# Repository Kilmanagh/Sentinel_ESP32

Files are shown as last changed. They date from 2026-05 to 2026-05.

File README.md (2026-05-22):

# Sentinel ESP32

Sentinel is an ESP32-based multi-sensor node built around ESPHome and Home Assistant.

The active implementation lives in `esphome/sentinel.yaml`. The old PlatformIO project in `pio-ARCHIVE/` is deprecated and is no longer the source of truth.

## Current firmware

- Active config: `esphome/sentinel.yaml`
- Secrets file: `esphome/secrets.yaml`
- Board target: `esp32dev`
- Framework: ESPHome on Arduino
- Home Assistant integration: native ESPHome API
- Device services: Wi-Fi, OTA, web server, local fallback AP, and Home Assistant entity-based runtime tuning

## Features

- BME280 environment telemetry
- AM312 PIR motion detection with warmup, stable-detect, stable-clear, and hold timing
- MAX9814 sound intrusion detection using peak-to-peak sampling
- Reed switch door state reporting
- Sound-level calibration helpers and approximate dB display
- Smoke alarm tone and cadence detection
- Device-health diagnostics and fault indicators
- Three-pixel WS2812 status LED strip plus onboard status LED
- Runtime tuning through Home Assistant entities exposed by ESPHome

## Primary docs

- `docs/Adjustments.MD` - active ESPHome tuning, calibration, and sensor-behavior guide
- `docs/Hardware_Deliverables.md` - current hardware, pin mapping, and LED wiring summary
- `hardware/Sentinel_Baseplate_Kit_Wiring.md` - practical baseplate / Dupont wiring guide for the actual 30-pin ESP32 board and expansion kit
- `hardware/Sentinel_Baseplate_Kit_Wiring.md` also includes a Sentinel-only pin map and a first bring-up checklist for bench validation
- `docs/Sentinel_Home_Assistant_Helpers.md` - optional Home Assistant helper package for counters, mode helpers, and last-event tracking
- `docs/Sentinel_Lovelace_Dashboard.md` - dashboard layout, setup, and troubleshooting view
- `docs/Sentinel_Lovelace_Dashboard.yaml` - Lovelace YAML for the dashboard itself

## Deploy

Use ESPHome to validate and install `esphome/sentinel.yaml`.

Typical workflow:

1. Fill in `esphome/secrets.yaml` with your Wi-Fi credentials.
2. Open `esphome/sentinel.yaml` in ESPHome or the Home Assistant ESPHome add-on.
3. Validate the config.
4. Install over USB for first flash, then use OTA afterward if desired.

## Notes

- The active docs no longer use the old MQTT, serial `cfg`, or BLE watchlist workflow.
- If you need historical PlatformIO material, keep it isolated under `pio-ARCHIVE/`.

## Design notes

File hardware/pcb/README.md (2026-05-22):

# PCB Package

This directory holds PCB fabrication package assets.

## Current recommendation

For the current Sentinel hardware build, do not treat this folder as the primary assembly path.

The recommended real-world build is:

- the existing AITRIP ESP32 baseplate / expansion kit
- Dupont wiring
- the practical wiring guide in `hardware/Sentinel_Baseplate_Kit_Wiring.md`

This `hardware/pcb/` folder should currently be treated as an experimental custom-board branch and documentation artifact, not the default build path.

## Current source

- `Sentinel_Passive_Carrier.kicad_pcb`: generated KiCad board source for a passive carrier board
- `generate_passive_carrier.py`: reproducible pcbnew generator for the current board source
- `Sentinel_Passive_Carrier_drc.rpt`: latest KiCad DRC report

## Current design scope

This is a passive carrier board derived from the current wiring, schematic, and enclosure documentation.

It assumes:

- ESP32 DevKit remains off-board and connects through a wire harness header rather than a direct socket footprint
- BME280, AM312, MAX9814, reed switch, and LED strip land on generic header / terminal positions
- board outline is sized conservatively to fit within the current 95 mm x 65 mm enclosure envelope

It is useful for:

- preserving the custom PCB experiment
- future routing / layout work
- exporting fabrication files for review while the design is still being corrected

It is not yet the recommended path for:

- immediate hardware assembly
- ordering production boards
- using as the single source of truth for the active build

## Fabrication package

The `gerbers/` folder now contains real KiCad exports for the passive carrier board, including:

- copper layers
- solder mask layers
- silkscreen layers
- edge cuts
- Excellon drill file
- drill map and drill report
- KiCad gerber job file

## Validation status

The fabrication package is generated from a real board source, but the current carrier layout is not yet fully DRC-clean.

Practical meaning:

- the files are real KiCad exports
- the board is still not ready to be treated as fabrication-safe
- the DRC report must be resolved before any board order is placed

Until that happens, the active hardware reference remains the baseplate / Dupont path documented in `hardware/Sentinel_Baseplate_Kit_Wiring.md`.

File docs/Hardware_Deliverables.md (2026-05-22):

# Sentinel ESP32 Hardware Deliverables

This document outlines the current hardware components and wiring configuration for the active ESPHome-based Sentinel ESP32 node.

## Bill of Materials (BOM)

- **Microcontroller**: AITRIP ESP-WROOM-32 / ESP-32S Type-C CH340C development board, 30-pin ESP32 DevKit V1 style header layout
- **Environmental Sensor**: BME280, 3.3V I2C
- **Motion Sensor**: AM312 mini PIR, powered from 3.3V
- **Acoustic Sensor**: MAX9814 microphone amplifier, analog output to GPIO 34
- **Security Sensor**: MC-38 magnetic reed switch, normally closed, signal to GPIO 32
- **Onboard Status LED**: ESP32 onboard LED on GPIO 2
- **External Status LEDs**: 3 x WS2812 addressable LEDs chained on GPIO 25 data
- **Recommended LED protection**: 330-470 ohm series resistor on the GPIO 25 data line and 470-1000 uF capacitor across LED 5V and GND

## Hardware Configuration And Pin Mapping

The active ESPHome build uses a mixed power layout:

- Sensors use the ESP32 regulated 3.3V rail
- The external WS2812 status LED chain uses the board 5V or VIN rail
- All devices must share a common ground

### Confirmed Dev Board Header Layout

The actual board shown by the user is the common 30-pin ESP32 DevKit V1 / ESP-32S style board, not the 38-pin Espressif DevKitC layout.

With the module antenna on the left and the USB Type-C connector on the right, the header labels are:

- Top row, left to right: `3V3`, `GND`, `D15`, `D2`, `D4`, `RX2`, `TX2`, `D5`, `D18`, `D19`, `D21`, `RX0`, `TX0`, `D22`, `D23`
- Bottom row, left to right: `EN`, `VP`, `VN`, `D34`, `D35`, `D32`, `D33`, `D25`, `D26`, `D27`, `D14`, `D12`, `D13`, `GND`, `VIN`

For Sentinel, the important physical header locations are:

- `3V3`: top row, pin 1 from the left
- `GND`: top row, pin 2 from the left or bottom row, pin 14 from the left
- `VIN` / 5V: bottom row, pin 15 from the left
- `GPIO34`: bottom row, pin 4 from the left (`D34`)
- `GPIO32`: bottom row, pin 6 from the left (`D32`)
- `GPIO25`: bottom row, pin 8 from the left (`D25`)
- `GPIO27`: bottom row, pin 10 from the left (`D27`)
- `GPIO21`: top row, pin 11 from the left (`D21`)
- `GPIO22`: top row, pin 14 from the left (`D22`)
- `GPIO2`: top row, pin 4 from the left (`D2`)

| Hardware Component | Component Pin | ESP32 GPIO / Pin | Active ESPHome Use | Pin Type |
| :--- | :--- | :--- | :--- | :--- |
| **BME280** | SDA | **GPIO 21** | `i2c.sda` | I2C Data |
| **BME280** | SCL | **GPIO 22** | `i2c.scl` | I2C Clock |
| **AM312 PIR** | OUT | **GPIO 27** | `pir_raw` | Digital Input |
| **MC-38 Reed Switch (NC)** | Signal | **GPIO 32** | `Door` | Digital Input with Pull-up |
| **MAX9814** | OUT | **GPIO 34** | sound sampling path | Analog Input |
| **Onboard LED** | Internal LED | **GPIO 2** | `status_led` | Digital Status Output |
| **WS2812 LED Chain** | DIN (LED 1) | **GPIO 25** | `Status LEDs` | Addressable LED Data |

## Wiring Connection Notes

- **Sensor Power**: Connect the BME280, AM312 PIR, and MAX9814 to the **3.3V** rail and **GND**.
- **Reed Switch**: Connect one MC-38 wire to **GPIO 32** and the other to **GND**. The active ESPHome config enables the internal pull-up, so the closed switch reads low when the magnet is present.
- **Analog Input**: GPIO 34 is input-only on the ESP32 and is appropriate for the MAX9814 analog output.
- **WS2812 Status LEDs**: The external 3-pixel LED chain is not powered from 3.3V. Use the ESP32 board **5V** or **VIN** rail for LED power, connect LED ground to the shared ground rail, and feed LED 1 data from **GPIO 25**.
- **LED Data Chain**: `GPIO25 -> DIN LED 1 -> DOUT LED 1 -> DIN LED 2 -> DOUT LED 2 -> DIN LED 3`.
- **LED Color Order**: The current ESPHome build expects `GRB` for the WS2812 chain.
- **Onboard LED vs External LEDs**: The node uses both the onboard GPIO 2 LED and the external 3-pixel WS2812 chain. The onboard LED is the basic ESPHome status LED, while the three external LEDs provide the main left, center, and right status display described elsewhere in the project docs.

### Final Expected Connections

| Sentinel function | Connect to | Power source |
| :--- | :--- | :--- |
| BME280 SDA | `D21` | `3.3V` |
| BME280 SCL | `D22` | `3.3V` |
| AM312 PIR OUT | `D27` | `3.3V` |
| MAX9814 OUT | `D34` | `3.3V` |
| MC-38 reed wire 1 | `D32` | none |
| MC-38 reed wire 2 | `GND` | none |
| WS2812 DIN | `D25` through `330-470 ohm` series resistor | n/a |
| WS2812 power | dedicated `5V` breakout or `VIN` | `5V` |
| WS2812 ground | `GND` | common ground |

For the baseplate / expansion kit build, keep the baseplate `V` jumper set to `3.3V` so the shared `V` row remains safe for the BME280, PIR, and MAX9814. Do not power the WS2812 strip from that shared `V` row.

## Current Firmware-Relevant Hardware Notes

- The active build exposes a `Door` binary sensor on GPIO 32.
- The active build drives `Status LEDs` as a 3-pixel WS2812 strip on GPIO 25.
- The active build still uses the onboard GPIO 2 LED through the ESPHome `status_led` component.
- Sound detection is no longer described by a single fixed firmware constant in documentation. Thresholds such as `Sound Threshold ADC` are runtime-adjustable through ESPHome and Home Assistant.

## Design And Fabrication Assets

- **Wiring Reference**: `hardware/Sentinel_Wiring.md`
- **Baseplate Build Guide**: `hardware/Sentinel_Baseplate_Kit_Wiring.md`
- **Enclosure Notes**: `hardware/3D Enclosure/Sentinel_Enclosure.md` and `hardware/3D Enclosure/Sentinel_Enclosure_Specs.md`
- **Schematic Notes**: `hardware/schematics/`
- **PCB Layout Notes**: `hardware/pcb/`
- **Manufacturing Files**: `hardware/pcb/gerbers/`

The active physical build reference is the baseplate / Dupont path in `hardware/Sentinel_Baseplate_Kit_Wiring.md`. The PCB layout and gerber outputs remain experimental reference assets until the passive carrier board is fully DRC-clean.

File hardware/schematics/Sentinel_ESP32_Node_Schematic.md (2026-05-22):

# Sentinel ESP32 Node Schematic Reference

This document describes the current schematic intent for the active Sentinel ESP32 node hardware.

## 1. Core Blocks
- ESP32 development board / module
- 3.3V sensor rail for BME280, AM312, and MAX9814
- 5V rail for the external 3-pixel WS2812 status LED chain
- Shared ground rail across ESP32, sensors, reed switch, and LED chain
- I2C environmental sensing on GPIO21 / GPIO22
- Digital inputs for PIR and reed switch
- Analog input for MAX9814 on GPIO34
- Onboard status LED on GPIO2
- External addressable LED data output on GPIO25

## 2. Required Outputs
Export final schematic as:
- PDF for review
- Source project file from the chosen EDA tool

## 3. Power Architecture
- Main power input: USB 5V through the ESP32 development board
- Sensor rail: regulated 3.3V from the ESP32 `3V3` pin
- LED rail: ESP32 board `5V` or `VIN` to the external WS2812 chain
- Grounding: all modules must share common ground

This is no longer a single-rail all-3.3V design. The external status LEDs are the main exception and must stay on the 5V rail.

## 4. Signal And Power Map

| Component | Pin / Connection | ESP32 GPIO or Rail | Notes |
| :--- | :--- | :--- | :--- |
| **BME280** | SDA | **GPIO 21** | I2C data |
| **BME280** | SCL | **GPIO 22** | I2C clock |
| **BME280** | VCC | **3V3** | Breakout board supply |
| **BME280** | GND | **GND** | Shared ground |
| **AM312 PIR** | OUT | **GPIO 27** | Digital motion input |
| **AM312 PIR** | VCC | **3V3** | Sensor supply |
| **AM312 PIR** | GND | **GND** | Shared ground |
| **MAX9814** | OUT | **GPIO 34** | ADC1 analog input |
| **MAX9814** | VCC | **3V3** | Sensor supply |
| **MAX9814** | GND | **GND** | Shared ground |
| **MC-38 Reed Switch** | Signal | **GPIO 32** | Uses internal pull-up |
| **MC-38 Reed Switch** | Return | **GND** | Closed switch pulls low |
| **Onboard LED** | Internal LED | **GPIO 2** | ESP32 board LED |
| **WS2812 Chain** | DIN (LED 1) | **GPIO 25** | External 3-pixel data input |
| **WS2812 Chain** | VCC | **5V / VIN** | External LED power |
| **WS2812 Chain** | GND | **GND** | Must share ESP32 ground |

## 5. External LED Chain Requirements
- LED chain size: 3 x WS2812
- Physical intent: one intact 3-LED strip used for left / center / right status indication
- Data path: `GPIO25 -> series resistor -> DIN LED 1 -> DOUT LED 1 -> DIN LED 2 -> DOUT LED 2 -> DIN LED 3`
- Recommended series resistor on data line: `330-470 ohm`
- Recommended bulk capacitor across LED power input: `470-1000 uF` between `5V` and `GND`
- Expected firmware color order: `GRB`

## 6. Functional Notes By Circuit

### BME280
- Uses the shared I2C bus on GPIO21 / GPIO22
- Typical pull-ups are usually present on the breakout board

### AM312 PIR
- Powered from 3.3V
- Output is read as a digital input on GPIO27

### MAX9814
- Output feeds GPIO34, which is input-only and part of ADC1
- Gain pin can remain floating for default gain, or be tied low if reduced gain is preferred

### MC-38 Reed Switch
- One side to GPIO32, the other side to ground
- Logic is normally closed, so the closed door state pulls the input low when the magnet is present

### Status Indicators
- GPIO2 remains the ESP32 onboard status LED path
- GPIO25 drives the external 3-pixel WS2812 chain used by the enclosure window group

## 7. Layout Notes
- Keep the BME280 thermally separated from the ESP32 module
- Keep the microphone close to the enclosure acoustic port
- Keep the WS2812 data resistor close to LED 1 input if possible
- Place the LED bulk capacitor close to the 5V entry point for the LED chain
- Keep the LED chain ground tied solidly to the ESP32 ground reference

## 8. Source Files In This Folder
- `Sentinel_ESP32_Node.kicad_sch`: KiCad source scaffold for the current hardware revision
- `Sentinel_KiCad_Netlist.net`: machine-style connectivity reference derived from the same hardware intent
- `Sentinel_ESP32_Node_Schematic.md`: human-readable schematic reference
- `Sentinel_Schematic_BOM.md`: build-oriented reference designator, connector, and harness table

## 9. Scope
This file is the human-readable schematic reference for the current hardware. The KiCad source scaffold lives in `Sentinel_ESP32_Node.kicad_sch`, the machine-style net connectivity reference lives in `Sentinel_KiCad_Netlist.net`, and the build-oriented connector/BOM table lives in `Sentinel_Schematic_BOM.md`.

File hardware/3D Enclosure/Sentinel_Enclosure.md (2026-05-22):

# Sentinel ESP32 Enclosure Guide

This file covers assembly, installation, and service notes for the current `v2_7` enclosure layout.

## 1. What This Guide Covers
- Base and lid assembly order
- Sensor placement behind the existing lid openings
- LED strip placement behind the 3-window status bar
- Service considerations when reopening the case

For dimensions and exact feature locations, use `Sentinel_Enclosure_Specs.md`.

## 2. Assembly Order
1. Mount the ESP32 DevKit in the main chamber and confirm the USB connector aligns with the side cutout.
2. Place the BME280 in the isolated vented chamber on the right side of the enclosure so it stays separated from ESP32 heat.
3. Route reed-switch wiring through the side notch before final closure.
4. Seat the PIR module so the AM312 lens aligns cleanly with the 12.5 mm lid opening.
5. Seat the MAX9814 microphone so the mic element is centered behind the 4.5 mm acoustic opening.
6. Fit the 3-LED status strip into the `v2_7` horizontal retainer behind the three LED windows.
7. Verify that LED wiring sits in the side wire-relief areas and does not push the strip out of the retainer.
8. Close the enclosure with the screw-fastened lid.

## 3. LED Bar Notes For v2_7
- The `v2_7` lid is designed around one intact horizontal 3-LED strip, not three separate single-LED holders.
- The visible order is left / center / right across the front bezel.
- The LED bar is intentionally placed low on the lid to preserve clearance from the PIR opening.
- Internal baffles separate the three LED windows to reduce light bleed.

## 4. Sensor Placement Notes
- PIR: keep the lens square to the lid opening and avoid forcing the board at an angle.
- Mic: a thin foam gasket or tape spacer can help keep the microphone aligned and reduce internal echo.
- BME280: keep the vent path open and avoid bunching cable slack inside the isolated chamber.

## 5. Wall Mount Use
- The base includes two back-panel keyholes for wall mounting.
- Test screw-head fit against the printed keyholes before final installation.
- Keep cable exits oriented so the enclosure can sit flat against the wall.

## 6. Service / Reopening
1. Disconnect USB power before opening the case.
2. Remove the lid screws before lifting the lid.
3. Lift slowly so the PIR, microphone, and LED wiring are not strained.
4. Clear dust from the vented BME chamber with air only; avoid pushing debris deeper into the slots.

## 7. Scope
This file is worth keeping only as the practical guide. It should not duplicate raw dimensions or SCAD geometry values from `Sentinel_Enclosure_Specs.md`.

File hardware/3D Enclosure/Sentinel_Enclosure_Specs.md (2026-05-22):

# Sentinel ESP32 Enclosure Specifications

This document captures the current mechanical design represented by the `v2_7` enclosure files in this folder.

## 1. Current Design Files
- Primary lid/base model: `Openscad_LED_Lid_v2_7_barholder.scad`
- Preview image: `Openscad_LED_Lid_v2_7.png`
- Exported print mesh: `Openscad_LED_Lid_v2_7_barholder.stl`
- Reference guide mesh: `Sentinel_Enclosure_Guide.stl`

## 2. Overall Envelope
- External size: 95 mm (L) x 65 mm (W) x 35 mm (H)
- Nominal wall thickness: 2.0 mm
- Screw pillar diameter: 8.0 mm
- Screw clearance hole diameter: 3.2 mm
- Internal divider wall: 2.0 mm thick

## 3. Base Features
- Four screw pillars at the corners for a screw-fastened lid
- Rear/side USB cutout sized by the SCAD slot at `12 mm x 8 mm`
- Reed-switch cable exit notch on the opposite side wall
- BME280 isolation chamber formed by the internal divider near the right side of the enclosure
- Vent slots on both right-side walls for the isolated environmental chamber
- Two wall-mount keyholes in the back panel

## 4. Lid Features
### PIR opening
- 12.5 mm round opening
- Centered at `x = 30`, `y = 32.5`

### Microphone opening
- 4.5 mm round opening
- Centered at `x = 55`, `y = 32.5`

### Status LED window group
- Design intent: one intact 3-LED horizontal bar holder
- LED bar center: `x = 39`, `y = 16`
- Nominal LED strip footprint: `30 mm x 15 mm`
- Three visible windows for left / center / right status indication
- Window centers:
	- Left: `x = 29`, `y = 16`
	- Center: `x = 39`, `y = 16`
	- Right: `x = 49`, `y = 16`
- Individual window size: `5 mm x 5 mm` with rounded corners
- Front bezel size: `36 mm x 12 mm`

## 5. Internal LED Retainer Intent
- Thin backing shelf for the full strip
- Bottom ledge supporting the strip from below
- Left and right side stops
- Two top tabs near the strip ends
- Left and right wire-relief notches
- Two internal light baffles between the three windows

## 6. Print Notes
- Recommended material: PETG or PLA
- Suggested infill: about 20%
- Add supports only where your slicer needs help around the side cutouts and keyholes
- Keep the lid face orientation consistent with the desired finish on the PIR, mic, and LED window side

## 7. Scope
This file is the mechanical reference for dimensions, openings, and enclosure features. Assembly and service steps belong in `Sentinel_Enclosure.md`.

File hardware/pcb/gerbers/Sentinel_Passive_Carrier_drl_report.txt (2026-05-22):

Drill report for Sentinel_Passive_Carrier.kicad_pcb
Created on 2026-05-22T07:55:04

Copper Layer Stackup:
    =============================================================
    L1 :  F.Cu                      front
    L2 :  B.Cu                      back

Drill file 'Sentinel_Passive_Carrier.drl' contains
    plated through holes:
    =============================================================
    T1  0.900mm  0.0354"  (2 holes))
    T2  1.000mm  0.0394"  (25 holes))
    T3  1.200mm  0.0472"  (3 holes))

    Total plated holes count 30

Not plated through holes are merged with plated holes
    unplated through holes:
    =============================================================

    Total unplated holes count 0

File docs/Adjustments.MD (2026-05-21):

# Sensor Adjustments

This guide covers the active ESPHome-based Sentinel node defined in `esphome/sentinel.yaml`.

It applies to the current ESPHome build only. The old PlatformIO project in `pio-ARCHIVE/` is deprecated and intentionally excluded from this guide.

## What Is Adjustable

The active ESPHome node exposes these user-tunable features through Home Assistant:

- PIR motion timing
- Sound intrusion timing and thresholding
- Sound-level calibration helpers
- Smoke alarm tone and cadence detection
- Status LED automatic behavior
- Sensor enable and disable switches

The live hardware and runtime surface in the ESPHome build also includes:

- BME280 temperature, humidity, pressure, comfort, and air-quality telemetry
- Reed-switch door state
- Device-health diagnostics
- WS2812 status LEDs

## Where To Adjust Things

Adjustments are made through the ESPHome entities exposed to Home Assistant.

There is no active serial `cfg` workflow, MQTT runtime config path, or BLE beacon watchlist in the current ESPHome implementation.

Most tuning values are exposed as `number`, `switch`, `select`, `button`, `sensor`, `binary_sensor`, or `text_sensor` entities. Values marked with `restore_value` or backed by restored globals survive reboot.

## Sensor Enable Switches

These switches control whether the related logic is running:

- `Enable PIR Sensing`
- `Enable Sound Sensing`
- `Enable Smoke Alarm Sensing`
- `Enable Status LEDs Auto`

Notes:

- Turning off `Enable PIR Sensing` clears the current motion state and stops PIR processing.
- Turning off `Enable Sound Sensing` clears sound and smoke-related runtime states because smoke detection depends on the microphone path.
- `Enable Smoke Alarm Sensing` only enables the smoke detector logic. It still depends on `Enable Sound Sensing` being on.
- `Enable Status LEDs Auto` switches the LED strip between automatic status display and manual effect testing.

## PIR Motion Sensor

The PIR logic in `esphome/sentinel.yaml` uses warmup, stable-detect timing, stable-clear timing, and hold time instead of treating the sensor as a simple immediate on or off edge.

### Home Assistant entities

- `Enable PIR Sensing`
- `PIR Warmup`
- `PIR Detect Stable`
- `PIR Clear Stable`
- `PIR Hold`
- `Motion`
- `PIR Stuck High Fault`

### Defaults from the ESPHome config

- `PIR Warmup = 30000 ms`
- `PIR Detect Stable = 150 ms`
- `PIR Clear Stable = 1500 ms`
- `PIR Hold = 5000 ms`

### What each setting does

- `PIR Warmup`: Ignore PIR activity for this long after boot or after PIR sensing is re-enabled.
- `PIR Detect Stable`: PIR must stay high for at least this long before `Motion` turns on.
- `PIR Clear Stable`: PIR must stay low for at least this long before the system considers clearing motion.
- `PIR Hold`: Once motion is valid, keep `Motion` on for at least this long after the last qualifying high period.

### How to tune PIR

If motion chatters or flickers:

- Raise `PIR Detect Stable`
- Raise `PIR Clear Stable`
- Raise `PIR Hold`

If motion feels too slow:

- Lower `PIR Detect Stable`
- Lower `PIR Hold`

If motion clears too quickly when a person pauses:

- Raise `PIR Clear Stable`
- Raise `PIR Hold`

If the PIR takes too long to become usable after restart:

- Lower `PIR Warmup` carefully

### Recommended PIR adjustment order

1. Leave `PIR Warmup` alone unless startup behavior is the real problem.
2. Adjust `PIR Detect Stable` first to control false triggers.
3. Adjust `PIR Clear Stable` next to stop clear and re-detect chatter.
4. Adjust `PIR Hold` last for the Home Assistant experience you want.

## Door Sensor

The current ESPHome build exposes a `Door` binary sensor from the reed switch.

There are no runtime adjustment entities for the door input in the current ESPHome config. If door behavior needs to change, that requires editing `esphome/sentinel.yaml` rather than tuning from Home Assistant.

## Sound Sensor

The MAX9814 microphone path uses peak-to-peak ADC swing over a sample window. The current ESPHome build does not treat the biased analog signal as a directly meaningful raw loudness value.

The important distinction is:

- `Sound Threshold ADC` controls whether `Sound Intrusion` turns on
- `Sound Level Floor ADC` and `Sound Level Ceiling ADC` only control relative sound display scaling

### Home Assistant entities

Core sound detection:

- `Enable Sound Sensing`
- `Sound Sample Window`
- `Sound Hold`
- `Sound Threshold ADC`
- `Sound Intrusion`

Calibration and display helpers:

- `Sound Level Floor ADC`
- `Sound Level Ceiling ADC`
- `Sound dB Floor`
- `Sound dB Ceiling`
- `Sound Calibration Capture Duration`
- `Capture Quiet Baseline`
- `Capture Loud Reference`
- `Sound Calibration Status`
- `Sound Calibration Captured Peak`
- `Sound Peak ADC`
- `Sound Min ADC`
- `Sound Max ADC`
- `Sound Level %`
- `Sound Approx dB`

### Defaults from the ESPHome config

- `Sound Sample Window = 100 ms`
- `Sound Hold = 3000 ms`
- `Sound Threshold ADC = 1200`
- `Sound Level Floor ADC = 60`
- `Sound Level Ceiling ADC = 1800`
- `Sound dB Floor = 35`
- `Sound dB Ceiling = 90`
- `Sound Calibration Capture Duration = 10000 ms`

### What each setting does

- `Sound Sample Window`: How long the ESP32 samples audio before evaluating the current peak-to-peak swing.
- `Sound Hold`: How long `Sound Intrusion` remains on after a valid event.
- `Sound Threshold ADC`: Minimum peak-to-peak swing needed to declare a sound intrusion.
- `Sound Level Floor ADC`: Peak-to-peak value treated as `0%` sound.
- `Sound Level Ceiling ADC`: Peak-to-peak value treated as `100%` sound.
- `Sound dB Floor`: Approximate dB mapped to `0%` sound.
- `Sound dB Ceiling`: Approximate dB mapped to `100%` sound.
- `Sound Calibration Capture Duration`: How long the guided quiet and loud capture buttons listen before saving a result.

### How to tune sound intrusion

If ordinary room noise triggers `Sound Intrusion`:

- Raise `Sound Threshold ADC`
- Raise `Sound Sample Window` slightly if short spikes are the problem

If sharp impacts are missed:

- Lower `Sound Threshold ADC`
- Lower `Sound Sample Window` if you need to catch faster transients

If the sound event clears too fast:

- Raise `Sound Hold`

If the sound event stays active too long:

- Lower `Sound Hold`

### Recommended sound adjustment order

1. Adjust `Sound Threshold ADC` first.
2. Adjust `Sound Sample Window` second.
3. Adjust `Sound Hold` last for the event duration you want in Home Assistant.

## Calibrating Sound Level Percent And Approx dB

These calibration entities are optional. They improve the usefulness of the relative sound display, but they do not decide whether `Sound Intrusion` triggers.

### Assisted calibration

1. Set `Sound Calibration Capture Duration` to a useful window such as `10000 ms`.
2. Keep the room in its normal quiet state.
3. Press `Capture Quiet Baseline`.
4. Wait for `Sound Calibration Status` to return to `Idle`.
5. The result is written into `Sound Level Floor ADC`.
6. Create a repeatable loud reference near the device.
7. Press `Capture Loud Reference`.
8. Wait for `Sound Calibration Status` to return to `Idle`.
9. The result is written into `Sound Level Ceiling ADC`.
10. Fine-tune `Sound Level Floor ADC`, `Sound Level Ceiling ADC`, and `Sound Threshold ADC` manually if needed.

During capture, `Sound Calibration Captured Peak` shows the highest peak seen so far.

### Direct manual calibration

1. Let the room settle into its normal quiet state.
2. Watch `Sound Peak ADC` for a while and note the typical quiet value.
3. Set `Sound Level Floor ADC` slightly above that baseline.
4. Create a repeatable loud sound you care about.
5. Watch `Sound Peak ADC` and note the typical loud value.
6. Set `Sound Level Ceiling ADC` near that loud value.
7. Choose a reasonable `Sound dB Floor` and `Sound dB Ceiling` pair if you want an approximate dB estimate.

Example starting point:

- Quiet room peak-to-peak: `60`
- Loud reference peak-to-peak: `1800`
- `Sound Level Floor ADC = 60`
- `Sound Level Ceiling ADC = 1800`
- `Sound dB Floor = 35`
- `Sound dB Ceiling = 90`

Important limits:

- The MAX9814 uses AGC, so absolute loudness is not stable like a calibrated sound meter.
- The ESP32 ADC is not a precision audio front end.
- `Sound Approx dB` is best treated as an automation-oriented estimate, not an instrument-grade reading.

## Smoke Alarm Sensing

The ESPHome build can run a best-effort smoke alarm detector from the microphone path. It looks for a combination of:

- sufficient sound strength
- energy near common alarm-tone frequencies
- repeated beep timing that matches an alarm pattern better than random room noise

This is useful for automations and notifications. It is not a certified life-safety detector.

### Home Assistant entities

- `Enable Smoke Alarm Sensing`
- `Smoke Alarm Profile`
- `Smoke Alarm Tone Threshold`
- `Smoke Alarm Min Peak ADC`
- `Smoke Alarm Hold`
- `Smoke Alarm Confirm Beeps`
- `Smoke Alarm Custom Tone 1`
- `Smoke Alarm Custom Tone 2`
- `Smoke Alarm Custom Tone 3`
- `Smoke Alarm Custom Min Beep Gap`
- `Smoke Alarm Custom Max Beep Gap`
- `Smoke Alarm Tone Score`
- `Smoke Alarm Beep Count`
- `Smoke Alarm Last Beep Age`
- `Smoke Alarm Detected`
- `Smoke Monitor Fault`

### Defaults from the ESPHome config

- `Enable Smoke Alarm Sensing = off`
- `Smoke Alarm Profile = Default`
- `Smoke Alarm Tone Threshold = 18`
- `Smoke Alarm Min Peak ADC = 250`
- `Smoke Alarm Hold = 15000 ms`
- `Smoke Alarm Confirm Beeps = 3`
- `Smoke Alarm Custom Tone 1 = 3000 Hz`
- `Smoke Alarm Custom Tone 2 = 3200 Hz`
- `Smoke Alarm Custom Tone 3 = 3400 Hz`
- `Smoke Alarm Custom Min Beep Gap = 250 ms`
- `Smoke Alarm Custom Max Beep Gap = 2000 ms`

### Smoke alarm profiles

The current select options are:

- `Default`
- `Generic Smoke`
- `Strict T3 Smoke`
- `Strict T4 CO`
- `Low Battery Chirp`
- `Custom`

Use the closest preset first before manually tuning thresholds.

### Recommended smoke alarm adjustment order

1. Turn on `Enable Smoke Alarm Sensing`.
2. Choose the closest `Smoke Alarm Profile`.
3. Test with a real alarm self-test tone if possible.
4. Watch `Smoke Alarm Tone Score`, `Smoke Alarm Beep Count`, and `Smoke Alarm Last Beep Age` while testing.
5. If you are using `Default` or `Custom`, adjust `Smoke Alarm Tone Threshold` so normal sounds stay below it and real alarm tones rise above it.
6. If you are using `Default` or `Custom`, adjust `Smoke Alarm Min Peak ADC` if distant speech or clatter still gets counted.
7. If you are using `Default` or `Custom`, adjust `Smoke Alarm Confirm Beeps` if you want detection faster or slower.
8. If you are using `Custom`, tune the three tone targets and the custom min and max gap values.
9. Adjust `Smoke Alarm Hold` last for Home Assistant event duration.

### How to read the smoke debug entities

- `Smoke Alarm Tone Score` should rise during a real alarm tone and stay lower during unrelated room sound.
- `Smoke Alarm Beep Count` should climb toward the configured confirmation count during a valid alarm sequence.
- `Smoke Alarm Last Beep Age` should stay relatively low while the alarm cadence continues, then grow once the sequence stops.
- `Smoke Monitor Fault` means smoke monitoring was enabled while sound sensing was not available.

If tone score rises but beep count does not, the cadence is not matching closely enough or the minimum peak threshold is still too strict.

## Device Health

The ESPHome build exposes health and fault entities so you can distinguish sensor tuning problems from connectivity or hardware faults.

### Home Assistant entities

- `Device Health`
- `Reset Reason`
- `Boot Count`
- `WiFi Connected`
- `API Connected`
- `WiFi Disconnect Count`
- `API Disconnect Count`
- `Heap Free`
- `Heap Min Free`
- `Heap Fragmentation`
- `Main Loop Time`
- `Environment Sensor Fault`
- `PIR Stuck High Fault`
- `Smoke Monitor Fault`
- `Memory Warning`

### What they mean

- `Device Health`: Summary state used by dashboards and automation logic. It can report states such as `Recovering After Boot`, `WiFi Reconnecting`, `WiFi OK / API Idle`, `Sensor Trouble`, `Low Memory`, `Memory Fragmented`, or `Healthy`.
- `Environment Sensor Fault`: The BME280 path is unavailable or returning invalid readings.
- `PIR Stuck High Fault`: The PIR input appears stuck high long enough to be suspicious.
- `Smoke Monitor Fault`: Smoke monitoring was enabled while the sound path was not active.
- `Memory Warning`: Heap free space or fragmentation has crossed the warning threshold.

### How to use them

- If `Device Health` stays on `Recovering After Boot`, the node is still settling after startup.
- If it shows `WiFi Reconnecting`, fix power or network quality before changing sensor thresholds.
- If it shows `WiFi OK / API Idle`, Wi-Fi is up but Home Assistant is not actively connected through the ESPHome API.
- If it shows `Sensor Trouble`, investigate the BME280, PIR state, or smoke-monitor dependency path before tuning detection values.
- If it shows `Low Memory` or `Memory Fragmented`, treat that as a stability warning.

## Status LEDs

The current ESPHome build drives a three-pixel WS2812 status strip on `GPIO25` by default.

### Home Assistant entities

- `Status LEDs`
- `Enable Status LEDs Auto`
- `Status LED Left Meaning`
- `Status LED Center Meaning`
- `Status LED Right Meaning`

### LED roles in auto mode

- Left LED: system, network, and overall health
- Center LED: live sensing activity
- Right LED: urgent alerts and sensor faults

### Manual test effects

When `Enable Status LEDs Auto` is off, the `Status LEDs` light can use these named effects:

- `Test System Healthy`
- `Test Network Reconnect`
- `Test API Idle`
- `Test Motion`
- `Test Sound`
- `Test Quiet Calibration`
- `Test Loud Calibration`
- `Test Smoke Alert`
- `Test Sensor Fault`
- `Test Memory Warning`
- `Test Rainbow`
- `Full Status Preview`

### Default auto color map

Left LED:

- Dim green: healthy idle
- Amber pulse: booting or PIR warmup
- Teal blink: Wi-Fi is up but no API client is connected
- Amber blink: Wi-Fi reconnecting
- Purple pulse: memory warning
- Red or amber failure indication: node status problem

Center LED:

- Off: idle
- Blue pulse: motion activity
- Orange pulse: sound activity
- Cyan pulse: quiet calibration capture
- Yellow pulse: loud calibration capture

Right LED:

- Off: no active alert
- Fast red flash: smoke alarm detected
- Yellow blink: sensor trouble

## Safe Tuning Workflow

Use this process for any sensor adjustment:

1. Change one value at a time.
2. Test with real behavior in the actual room.
3. Watch the related binary sensor, helper sensors, and fault indicators together.
4. Keep notes on what improved or got worse.
5. Only keep the change if the result is clearly better.

## Quick Reference

Use these when behavior looks wrong:

- False PIR triggers: raise `PIR Detect Stable`
- PIR clears too fast: raise `PIR Clear Stable` or `PIR Hold`
- PIR feels sluggish: lower `PIR Detect Stable`
- Sound triggers too easily: raise `Sound Threshold ADC`
- Sound misses sharp impacts: lower `Sound Threshold ADC` or shorten `Sound Sample Window`
- Sound event duration is wrong: adjust `Sound Hold`
- Smoke alarm detection false-triggers: raise `Smoke Alarm Tone Threshold`, `Smoke Alarm Min Peak ADC`, or `Smoke Alarm Confirm Beeps`
- Smoke alarm detection misses real tests: lower `Smoke Alarm Tone Threshold`, `Smoke Alarm Min Peak ADC`, or `Smoke Alarm Confirm Beeps`

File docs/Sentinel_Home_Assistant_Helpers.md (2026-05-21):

# Sentinel Home Assistant Helpers

This guide covers the pieces that are better kept in Home Assistant instead of pushed into the ESP32 firmware:

- event counters
- last-event tracking
- a simple mode selector

The example package file is:

- `home_assistant/sentinel_helpers_package.yaml`

## Why this split exists

The ESP32 firmware already carries the always-on sensing logic, signal processing, LED logic, and diagnostics. Counters, helper selectors, and timestamp bookkeeping are cheaper and easier to change in Home Assistant.

This keeps the node lighter while still giving you:

- per-event counters
- a last-event summary
- a mode helper that can turn the existing ESPHome switches on and off

## What stays on the ESP32

These remain firmware-side because they reflect device-local state or actions:

- fault flags such as `Environment Sensor Fault`, `PIR Stuck High Fault`, `Smoke Monitor Fault`, and `Memory Warning`
- maintenance actions such as `Capture Quiet Baseline`, `Capture Loud Reference`, `Reset Detection State`, and `Restart`

No new maintenance buttons were added because the existing ESPHome buttons already cover the current maintenance needs.

## Package install steps

1. Enable Home Assistant packages if you do not already use them.
2. Copy `home_assistant/sentinel_helpers_package.yaml` into your HA config packages directory.
3. Restart Home Assistant or reload YAML-based helpers and automations.
4. Confirm the new helpers appear.

Example `configuration.yaml` snippet:

```yaml
homeassistant:
  packages: !include_dir_named packages
```

## Helpers created by the package

Counters:

- `counter.sentinel_motion_events`
- `counter.sentinel_sound_events`
- `counter.sentinel_smoke_events`
- `counter.sentinel_door_events`

Last-event helpers:

- `input_text.sentinel_last_event`
- `input_datetime.sentinel_last_event_time`
- `sensor.sentinel_last_event_summary`

Mode helper:

- `input_select.sentinel_mode`

## Default mode mapping

The example mode selector drives the existing ESPHome switches with this mapping:

- `Disarmed`: PIR off, sound off, smoke off
- `Motion Only`: PIR on, sound off, smoke off
- `Motion + Sound`: PIR on, sound on, smoke off
- `Full Monitor`: PIR on, sound on, smoke on

If that mapping is too aggressive or too weak, edit the `choose:` block in `home_assistant/sentinel_helpers_package.yaml`.

## Entity ID assumptions

The example package assumes the default ESPHome entity IDs created from the current firmware, including:

- `binary_sensor.sentinel_motion`
- `binary_sensor.sentinel_sound_intrusion`
- `binary_sensor.sentinel_smoke_alarm_detected`
- `binary_sensor.sentinel_door`
- `switch.sentinel_enable_pir_sensing`
- `switch.sentinel_enable_sound_sensing`
- `switch.sentinel_enable_smoke_alarm_sensing`

If your Home Assistant instance renamed any of those, update the package before enabling it.

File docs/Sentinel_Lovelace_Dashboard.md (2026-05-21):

# Sentinel Lovelace Dashboard

This guide ships a clean Home Assistant Lovelace dashboard for the ESPHome Sentinel node.

Files:

- `docs/Sentinel_Lovelace_Dashboard.yaml` - built-in Lovelace dashboard YAML
- `docs/Adjustments.MD` - tuning and calibration reference

## Goal

The dashboard is split into three views so the device is easier to use day-to-day:

- `Overview` - live status, environment, sound, and smoke alarm readouts
- `Settings` - tuning values, sensing toggles, LED controls, calibration actions, and restart/reset controls
- `Troubleshooting` - high-signal debug readouts, LED checks, and recovery actions

## Why this layout works

Home Assistant device pages often mix editable numbers, action buttons, and live sensors together. That makes a heavily tunable device feel cluttered.

This dashboard separates them by intent:

- display what the room and device are doing right now
- adjust detection and calibration settings in one place
- troubleshoot false positives and missed detections without hunting through the device page

## Install

### Option 1: YAML dashboard

1. In Home Assistant, open `Settings > Dashboards`.
2. Create a new dashboard or open an existing YAML-mode dashboard.
3. Copy the contents of `docs/Sentinel_Lovelace_Dashboard.yaml` into the dashboard editor.
4. Save and reload the dashboard.

### Option 2: Manual card copy

If you do not want a full YAML dashboard, copy individual cards or sections from `docs/Sentinel_Lovelace_Dashboard.yaml` into a Lovelace view.

## Entity ID assumptions

The dashboard assumes your ESPHome device is named `Sentinel` and that Home Assistant generated entity IDs such as:

- `sensor.sentinel_temperature`
- `binary_sensor.sentinel_motion`
- `switch.sentinel_enable_sound_sensing`
- `button.sentinel_capture_quiet_baseline`

If your names differ, update the `entity:` lines in `docs/Sentinel_Lovelace_Dashboard.yaml`.

## Recommended use

### Overview view

Use this view for normal daily operation.

Focus on:

- `Motion`, `Door`, `Sound Intrusion`, `Smoke Alarm`
- `Temperature`, `Humidity`, `Pressure`, `Comfort Index`, `IAQ Score`
- `Sound Level %`, `Sound Approx dB`, `Smoke Alarm Tone Score`
- `Device Health`, `Status LED Left Meaning`, `Status LED Center Meaning`, `Status LED Right Meaning`, `Status LEDs`, `Enable Status LEDs Auto`

### Settings view

Use this view when you are tuning behavior.

PIR settings:

- `PIR Warmup`
- `PIR Detect Stable`
- `PIR Clear Stable`
- `PIR Hold`

Sound settings:

- `Sound Sample Window`
- `Sound Hold`
- `Sound Threshold ADC`
- `Sound Level Floor ADC`
- `Sound Level Ceiling ADC`
- `Sound dB Floor`
- `Sound dB Ceiling`

Assisted calibration actions:

- `Capture Quiet Baseline`
- `Capture Loud Reference`
- `Sound Calibration Capture Duration`

Smoke alarm tuning:

- `Enable Smoke Alarm Sensing`
- `Smoke Alarm Tone Threshold`
- `Smoke Alarm Min Peak ADC`
- `Smoke Alarm Confirm Beeps`
- `Smoke Alarm Hold`

Status LED controls:

- `Enable Status LEDs Auto`
- `Status LEDs`
- `Status LED Left Meaning`
- `Status LED Center Meaning`
- `Status LED Right Meaning`
- the current `effect` attribute when you are testing patterns manually

### Troubleshooting view

Use this when a sensor seems wrong.

Helpful readouts:

- `Device Health`
- `Status LED Left Meaning`
- `Status LED Center Meaning`
- `Status LED Right Meaning`
- `Sound Peak ADC`
- `Sound Level %`
- `Sound Approx dB`
- `Smoke Alarm Tone Score`
- `Smoke Alarm Beep Count`
- `Smoke Alarm Last Beep Age`
- `Sound Calibration Status`
- `Sound Calibration Captured Peak`

Helpful LED checks:

- `Status LEDs`
- `Enable Status LEDs Auto`
- the active LED `effect` attribute

Helpful actions:

- `Capture Quiet Baseline`
- `Capture Loud Reference`
- `Reset Detection State`
- `Restart Device`

## Calibration workflow

### Sound level calibration

1. Open the `Settings` view.
2. Set `Sound Calibration Capture Duration` to something practical like `10000 ms`.
3. With the room quiet, press `Capture Quiet Baseline`.
4. Wait for `Sound Calibration Status` to return to `Idle`.
5. Create a repeatable loud sound and press `Capture Loud Reference`.
6. Wait for `Sound Calibration Status` to return to `Idle`.
7. Fine tune `Sound Level Floor ADC`, `Sound Level Ceiling ADC`, and `Sound Threshold ADC` manually.

Important distinction:

- `Sound Threshold ADC` controls detection
- `Sound Level Floor ADC` and `Sound Level Ceiling ADC` control percentage scaling

### Smoke alarm tuning

1. Turn on `Enable Smoke Alarm Sensing`.
2. Run a real alarm test tone if possible.
3. Watch `Smoke Alarm Tone Score`, `Smoke Alarm Beep Count`, and `Smoke Alarm Last Beep Age`.
4. Adjust `Smoke Alarm Tone Threshold`, `Smoke Alarm Min Peak ADC`, and `Smoke Alarm Confirm Beeps`.
5. Adjust `Smoke Alarm Hold` last.

## Troubleshooting

### Sound intrusion triggers too easily

- Raise `Sound Threshold ADC`
- Raise `Sound Sample Window` slightly if very short spikes are the issue
- Re-capture the quiet baseline if the room changed

### Sound intrusion misses obvious noise

- Lower `Sound Threshold ADC`
- Lower `Sound Sample Window` if you want sharper transient response
- Re-capture the loud reference if the current ceiling is too high or too low

### Sound level percentage looks wrong

- Re-capture the quiet baseline
- Re-capture the loud reference
- Manually fine tune `Sound Level Floor ADC` and `Sound Level Ceiling ADC`

### Smoke alarm false triggers

- Raise `Smoke Alarm Tone Threshold`
- Raise `Smoke Alarm Min Peak ADC`
- Raise `Smoke Alarm Confirm Beeps`

### Smoke alarm misses the test tone

- Lower `Smoke Alarm Tone Threshold`
- Lower `Smoke Alarm Min Peak ADC`
- Lower `Smoke Alarm Confirm Beeps`
- Confirm that `Smoke Alarm Tone Score` rises when the alarm sounds

### A detector seems stuck

Use `Reset Detection State` first. That clears live detection state without wiping your saved settings.

### The status LEDs are dark or the colors look wrong

- Confirm the LEDs are powered from `5V` and share `GND` with the ESP32
- Confirm the data chain order is `LED 1 -> LED 2 -> LED 3`
- If colors are swapped, adjust `status_pixel_rgb_order` in the ESPHome YAML
- Turn off `Enable Status LEDs Auto` and run `Full Status Preview` from the `Status LEDs` entity

## Notes

- This dashboard uses built-in Lovelace cards only.
- It is meant to complement the device page, not replace your tuning guide.
- If Home Assistant cached older entity categories or names, reload the ESPHome device or re-open the dashboard after updates.

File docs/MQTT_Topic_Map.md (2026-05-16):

# Sentinel ESP32 MQTT Topic Map

This document maps the MQTT topics and JSON structures used by the Sentinel ESP32 Node for communication with Home Assistant.

## Quick Start

Use this section when commissioning a node and you only need the most common topics.

### Core state topics

- `sentinel/<device_id>/status` - online/offline LWT state
- `sentinel/<device_id>/environment` - BME280 telemetry
- `sentinel/<device_id>/motion` - PIR motion state
- `sentinel/<device_id>/sound` - sound intrusion state and peak-to-peak ADC data
- `sentinel/<device_id>/door` - reed switch state
- `sentinel/<device_id>/ble_watchlist` - iBeacon watchlist presence summary and per-slot state
- `sentinel/<device_id>/diagnostics` - uptime, heap, RSSI, reconnect counters, IP, firmware

### Most-used runtime config topics

- `sentinel/<device_id>/config/pir_detect_stable_ms/set`
- `sentinel/<device_id>/config/pir_clear_stable_ms/set`
- `sentinel/<device_id>/config/pir_hold_ms/set`
- `sentinel/<device_id>/config/sound_threshold_adc/set`
- `sentinel/<device_id>/config/sound_sample_window_ms/set`
- `sentinel/<device_id>/config/sound_hold_ms/set`
- `sentinel/<device_id>/config/ble_beacon1_uuid/set`
- `sentinel/<device_id>/config/ble_beacon1_major/set`
- `sentinel/<device_id>/config/ble_beacon1_minor/set`

Each config key also has a matching `/state` topic.

### Home Assistant discovery pattern

- `homeassistant/<component>/<device_id>/<object_id>/config`

Discovery is published at boot and when runtime config discovery is refreshed.

## Topic Structure
All topics follow the base format: `sentinel/<device_id>/<subtopic>`
- `<device_id>` is the unique 12-character MAC address in lowercase (e.g., `4c11ae0d7604`).

## Sensors & Telemetry

### 1. Environment
**Topic:** `sentinel/<device_id>/environment`
- **Payload:** JSON
- **Frequency:** Every 30 seconds
- **Fields:**
  - `temperature_f`: float (Temperature in Fahrenheit)
  - `humidity`: float (Relative humidity percentage)
  - `pressure_hpa`: float (Atmospheric pressure in hPa)
  - `comfort_index`: float (Calculated comfort score 0-100)
  - `comfort_label`: string (e.g., "Excellent", "Good")
  - `iaq_score`: int (Indoor Air Quality score 0-100)
  - `iaq_label`: string (e.g., "Excellent", "Moderate")

### 2. Motion (PIR)
**Topic:** `sentinel/<device_id>/motion`
- **Payload:** JSON
- **Fields:**
  - `motion`: string ("detected" or "clear")

### 3. Sound (Intrusion)
**Topic:** `sentinel/<device_id>/sound`
- **Payload:** JSON
- **Fields:**
  - `intrusion`: string (`"detected"` or `"clear"`)
  - `peak_adc`: int (Peak-to-peak ADC span for the sample window)
  - `min_adc`: int (Lowest ADC sample seen in the window)
  - `max_adc`: int (Highest ADC sample seen in the window)

### 4. Door (Reed Switch)
**Topic:** `sentinel/<device_id>/door`
- **Payload:** JSON
- **Fields:**
  - `state`: string ("OPEN" or "CLOSED")
  - `raw`: int (0 for CLOSED, 1 for OPEN — logic adjusted for NC switch)

### 5. BLE Watchlist Presence
**Topic:** `sentinel/<device_id>/ble_watchlist`
- **Payload:** JSON
- **Frequency:** Every 2 minutes
- **Fields:**
  - `configured_count`: int (Configured watchlist slots)
  - `present_count`: int (Configured slots currently present)
  - `beacon1_name` ... `beacon4_name`
  - `beacon1_uuid` ... `beacon4_uuid`
  - `beacon1_major` ... `beacon4_major`
  - `beacon1_minor` ... `beacon4_minor`
  - `beacon1_present` ... `beacon4_present` (`home`, `away`, or `unconfigured`)
  - `beacon1_rssi` ... `beacon4_rssi`

## System & Diagnostics

### Status (LWT)
**Topic:** `sentinel/<device_id>/status`
- **Payload:** string ("online" or "offline")
- **Note:** Utilizes MQTT Last Will and Testament for disconnect detection.

### Diagnostics
**Topic:** `sentinel/<device_id>/diagnostics`
- **Payload:** JSON
- **Frequency:** Every 60 seconds
- **Fields:**
  - `uptime_sec`: int (Seconds since boot)
  - `uptime_fmt`: string (Human-readable uptime)
  - `free_heap`: int (Available RAM in bytes)
  - `min_free_heap`: int (Lowest observed free heap)
  - `rssi`: int (WiFi signal strength in dBm)
  - `wifi_reconnects`: int
  - `mqtt_reconnects`: int
  - `ip_address`: string
  - `mac`: string
  - `bme280_ok`: bool
  - `firmware`: string

## Runtime Config Topics

Runtime-tunable settings are exposed under:

- `sentinel/<device_id>/config/<key>/state`
- `sentinel/<device_id>/config/<key>/set`

Examples:

- `sentinel/<device_id>/config/pir_detect_stable_ms/state`
- `sentinel/<device_id>/config/sound_threshold_adc/set`
- `sentinel/<device_id>/config/ble_beacon1_uuid/state`
- `sentinel/<device_id>/config/ble_beacon1_major/set`
- `sentinel/<device_id>/config/ble_beacon1_minor/set`

## Home Assistant Auto-Discovery
**Topics:** `homeassistant/<component>/<device_id>/<object_id>/config`
- These topics are published at boot and whenever runtime config discovery is refreshed.

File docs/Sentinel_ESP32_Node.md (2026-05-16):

# Sentinel ESP32 Node Firmware

## Source and build

- Firmware source: `src/main.cpp`
- PlatformIO environment: `esp32dev`
- Board target: ESP32 Dev Module
- Serial monitor speed: `115200`

## Runtime behavior

The current firmware provides:

- BME280 environmental telemetry
- PIR motion detection on GPIO 27
- Reed switch door monitoring on GPIO 32
- MAX9814 sound intrusion detection on GPIO 34
- MQTT auto-discovery for Home Assistant
- NVS-backed runtime configuration
- BLE watchlist presence tracking using iBeacon `UUID + major + minor`

## Build

```powershell
& "$env:USERPROFILE\.platformio\penv\Scripts\platformio.exe" run -d "d:\Source Code\ESP32\Sent" -e esp32dev
```

## Flash

```powershell
& "$env:USERPROFILE\.platformio\penv\Scripts\platformio.exe" run -d "d:\Source Code\ESP32\Sent" -e esp32dev -t upload --upload-port COM6
```

## Serial config commands

Use the serial monitor at `115200` and send:

```text
cfg help
cfg show
cfg set <key> <value>
cfg save
cfg apply
cfg reset
```

Key runtime groups include:

- Wi-Fi, static IP, DNS, NTP, and MQTT settings
- PIR timing settings
- Sound detection settings
- `ble_beaconX_name`, `ble_beaconX_uuid`, `ble_beaconX_major`, `ble_beaconX_minor`

## BLE enrollment commands

If you need to discover a beacon identity before adding it to the watchlist:

```text
ble help
ble enroll on
ble enroll status
ble enroll off
```

While enrollment logging is enabled, the firmware prints entries like:

```text
[BLE][ENROLL] UUID:12345678-1234-1234-1234-1234567890AB Major:100 Minor:7 RSSI:-61
```

## Related docs

- `docs/Adjustments.MD` for tuning and BLE enrollment workflow
- `docs/MQTT_Topic_Map.md` for published topics and payloads

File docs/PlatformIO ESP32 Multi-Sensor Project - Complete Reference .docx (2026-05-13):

PlatformIO ESP32 Multi-Sensor Station

Complete Project Reference

Home Assistant Integration via MQTT Auto-Discovery

Version 1.0.0 | May 2026

A comprehensive, self-contained reference for building, flashing, and integrating an ESP32-based environmental monitoring station with Home Assistant.

## Project Overview

This document provides a complete reference for building an ESP32-based environmental monitoring station that reads multiple sensors—temperature, humidity, barometric pressure, ambient light level, and motion detection—and publishes the data to Home Assistant via MQTT with automatic entity discovery. The project is built using PlatformIO for professional, reproducible project management.

With MQTT Auto-Discovery, the ESP32 registers its sensor entities directly with Home Assistant. There is no manual YAML configuration required: power on the board, and your sensors appear in the Home Assistant UI within seconds.

### Key Features

- Multi-sensor support: BME280 (temperature, humidity, pressure), HC-SR501 PIR motion sensor, and LDR photoresistor for ambient light
- MQTT Auto-Discovery: Zero-config Home Assistant integration—entities appear automatically
- WiFi reconnection with exponential backoff: Resilient connectivity with progressive retry delays up to 30 seconds
- OTA (Over-the-Air) update support: Flash new firmware wirelessly without a USB cable
- Hardware watchdog timer: Automatic recovery from software hangs
- JSON-formatted sensor payloads: Clean, structured data for easy parsing
- LWT (Last Will and Testament): Automatic availability tracking—Home Assistant knows when the device goes offline
- Configurable reporting intervals: Adjust sensor read frequency via a single constant

═

═

═

═

═

═

PAGE BREAK

═

═

═

═

═

═

## Table of Contents

1. Project Overview

2. Bill of Materials

3. ESP32 Pinout Diagram & Wiring

3.1 ESP32 DevKit V1 Pin Reference

3.2 Wiring Diagram (Text-Based)

3.3 LDR Voltage Divider Circuit

4. PlatformIO Project Structure

5. Configuration Files

5.1 platformio.ini

5.2 secrets.h (Template)

5.3 config.h

6. Complete Source Code — main.cpp

7. MQTT Auto-Discovery Deep Dive

7.1 What is MQTT Auto-Discovery?

7.2 Discovery Topic Format

7.3 Discovery Payload Anatomy

7.4 The Device Block

7.5 Value Templates (Jinja2)

7.6 Availability & LWT

7.7 Removing Discovered Entities

8. Home Assistant Setup Guide

8.1 Installing Mosquitto Broker Add-on

8.2 Creating an MQTT User

8.3 Configuring the MQTT Integration

8.4 Verifying Entity Discovery

8.5 Adding Entities to Dashboards

8.6 Creating Automations with Motion Sensor

9. .gitignore File

10. Troubleshooting & FAQ

11. MQTT Topic Reference

12. Revision History & License

═

═

═

═

═

═

PAGE BREAK

═

═

═

═

═

═

# 2. Bill of Materials

The following components are required to build the complete multi-sensor station. All parts are widely available from electronics retailers and online marketplaces.

Component | Qty | Description | Typical Part Number / Notes
ESP32 DevKit V1 (38-pin) | 1 | Main microcontroller with WiFi and Bluetooth | ESP-WROOM-32 module
BME280 Sensor Module | 1 | Temperature, humidity, and barometric pressure (I2C) | GY-BME280 breakout board
PIR Motion Sensor | 1 | HC-SR501 passive infrared motion detector | Adjustable sensitivity and delay pots
LDR Photoresistor | 1 | Light-dependent resistor for ambient light sensing | GL5528 or similar
10kΩ Resistor | 1 | Pull-down for LDR voltage divider | 1/4W through-hole
Breadboard | 1 | Full-size solderless breadboard | 830 tie points
Jumper Wires | ~15 | Male-to-male and male-to-female | Various colors recommended for tracing
USB Micro-B Cable | 1 | Programming and power | Data-capable (not charge-only)
5V Power Supply (optional) | 1 | For standalone deployment | USB phone charger works (5V / 1A min)

Tip

When purchasing a USB cable, verify it supports data transfer. Many inexpensive cables are charge-only and will not allow firmware upload. If your computer does not detect the ESP32, try a different cable first.

═

═

═

═

═

═

PAGE BREAK

═

═

═

═

═

═

# 3. ESP32 Pinout Diagram & Wiring

## 3.1 ESP32 DevKit V1 Pin Reference

The following table lists every GPIO pin used in this project, its function, and the recommended wire color for easy visual tracing on your breadboard.

GPIO Pin | Function | Connected To | Wire Color | Notes
GPIO 21 (SDA) | I2C Data | BME280 SDA | Blue | Internal pull-up enabled
GPIO 22 (SCL) | I2C Clock | BME280 SCL | Yellow | Internal pull-up enabled
GPIO 27 | Digital Input | PIR OUT | Green | HC-SR501 signal pin
GPIO 34 | ADC Input | LDR Voltage Divider | Orange | ADC1_CH6, input-only pin
3V3 | Power Out | BME280 VCC | Red | 3.3V regulated output
5V / VIN | Power Out | PIR VCC | Red | 5V from USB power
GND | Ground | Common Ground Bus | Black | Shared ground for all components
GPIO 2 | Status LED | Onboard LED | — | Built-in on DevKit, active HIGH

Important

GPIO 34 is an input-only pin on the ESP32. It does not have an internal pull-up or pull-down resistor, which is why we use an external 10kΩ resistor in the voltage divider. Do not attempt to use GPIO 34 as an output.

## 3.2 Wiring Diagram (Text-Based)

The following ASCII diagram shows all connections between the ESP32 DevKit and the three sensor components. Follow this carefully when wiring your breadboard.

┌──────────────────────┐
│ ESP32 DevKit V1 │
│ │
│ 3V3 ──┬─────────────┼──── BME280 VCC (Red)
│ │ │
│ └─── LDR ─────┼──┐
│ │ │ (LDR top lead)
│ 5V ────────────────┼──┼── PIR VCC (Red)
│ │ │
│ GND ──┬─────────────┼──┼── BME280 GND (Black)
│ ├─────────────┼──┼── PIR GND (Black)
│ └─────────────┼──┼── 10kΩ bottom → GND (Black)
│ │ │
│ GPIO 21 (SDA) ──────┼──┼── BME280 SDA (Blue)
│ GPIO 22 (SCL) ──────┼──┼── BME280 SCL (Yellow)
│ │ │
│ GPIO 27 ────────────┼──┼── PIR OUT (Green)
│ │ │
│ GPIO 34 ────────────┼──┘ (Junction point)
│ │
│ GPIO 2 (onboard LED)│
└──────────────────────┘

╔═══════════════════════════════════════════════════════════╗
║ LDR VOLTAGE DIVIDER DETAIL ║
║ ║
║ 3.3V ───[ LDR ]───┬───[ 10kΩ ]─── GND ║
║ │ ║
║ └─── GPIO 34 (ADC read) ║
╚═══════════════════════════════════════════════════════════╝

╔═══════════════════════════════════════════════════════════╗
║ BME280 MODULE (4 pins) ║
║ ║
║ VCC ─── 3V3 SDA ─── GPIO 21 ║
║ GND ─── GND SCL ─── GPIO 22 ║
╚═══════════════════════════════════════════════════════════╝

╔═══════════════════════════════════════════════════════════╗
║ HC-SR501 PIR SENSOR (3 pins) ║
║ ║
║ VCC ─── 5V OUT ─── GPIO 27 ║
║ GND ─── GND ║
╚═══════════════════════════════════════════════════════════╝

## 3.3 LDR Voltage Divider Circuit

The LDR (Light-Dependent Resistor) cannot be read directly by the ESP32’s ADC. Instead, we create a voltage divider circuit with a fixed 10kΩ resistor. The circuit works as follows:

3.3V ───[ LDR (variable) ]───┬───[ 10kΩ (fixed) ]─── GND
│
└─── GPIO 34 (ADC input)

Voltage divider formula:

V_out = 3.3V × ( R_fixed / (R_LDR + R_fixed) )

Where:
R_fixed = 10,000 Ω (the fixed resistor)
R_LDR = varies with light (typically 1kΩ–10MΩ)
V_out = voltage at GPIO 34

How it works: In bright light, the LDR resistance drops (e.g., to ~1kΩ), so more voltage appears at the GPIO 34 junction—higher ADC readings. In darkness, the LDR resistance increases dramatically (e.g., to several MΩ), so nearly all voltage drops across the LDR and the GPIO 34 junction sees very little voltage—lower ADC readings.

The ESP32 ADC reads 0–4095 (12-bit resolution) corresponding to 0–3.3V. In the firmware, we map this range to an approximate lux value for Home Assistant.

═

═

═

═

═

═

PAGE BREAK

═

═

═

═

═

═

# 4. PlatformIO Project Structure

The project follows the standard PlatformIO directory layout. Below is the complete directory tree with annotations:

esp32-multi-sensor/
├── platformio.ini ← Project configuration (board, libs, build flags)
├── src/
│ └── main.cpp ← Main application source code
├── include/
│ ├── config.h ← Project constants and pin definitions
│ └── secrets.h ← WiFi/MQTT credentials (NEVER commit this file)
├── lib/
│ └── README ← Place for project-specific libraries
├── test/
│ └── README ← Place for unit tests
└── .gitignore ← Excludes secrets.h, .pio/, build artifacts

Directory / File | Purpose
platformio.ini | Defines the target board, framework, library dependencies, build flags, and monitor settings. This is the “project manifest.”
src/ | Contains application source files. For this project, everything is in main.cpp.
include/ | Header files for configuration and secrets. Keeps credentials separate from logic.
lib/ | Project-specific libraries (not used here; we use PlatformIO’s library manager instead).
test/ | Unit tests (optional). PlatformIO supports native and embedded test runners.
.gitignore | Prevents credentials and build artifacts from being committed to version control.

Warning

The file include/secrets.h contains your WiFi password, MQTT credentials, and OTA password. Never commit this file to a public repository. Always ensure it is listed in your .gitignore.

═

═

═

═

═

═

PAGE BREAK

═

═

═

═

═

═

# 5. Configuration Files

## 5.1 platformio.ini

This is the PlatformIO project configuration file. It defines the target hardware, framework, library dependencies, and build settings.

; ════════════════════════════════════════════════════════════════
; PlatformIO Configuration — ESP32 Multi-Sensor Station
; ════════════════════════════════════════════════════════════════

[env:esp32dev]
platform = espressif32
board = esp32dev
framework = arduino

; Serial monitor baud rate
monitor_speed = 115200

; Upload speed (max reliable speed for most USB-UART bridges)
upload_speed = 921600

; Library dependencies — managed by PlatformIO
lib_deps =
knolleary/PubSubClient@^2.8
adafruit/Adafruit BME280 Library@^2.2.4
adafruit/Adafruit Unified Sensor@^1.1.14
bblanchon/ArduinoJson@^7.0.0

; Build flags
build_flags =
-DCORE_DEBUG_LEVEL=1

; Serial monitor filters
monitor_filters = esp32_exception_decoder

## 5.2 secrets.h (Template with Placeholders)

Copy this template to include/secrets.h and fill in your actual credentials. This file must never be committed to version control.

// ════════════════════════════════════════════════════════════════
// secrets.h — Credential Template
// ════════════════════════════════════════════════════════════════
//
// ⚠️ TEMPLATE FILE — Copy to secrets.h and fill in your values
// ⚠️ Add secrets.h to .gitignore — NEVER commit credentials
//
// ════════════════════════════════════════════════════════════════

#pragma once

// ── WiFi Credentials ──────────────────────────────────────────
#define WIFI_SSID "YOUR_WIFI_SSID"
#define WIFI_PASSWORD "YOUR_WIFI_PASSWORD"

// ── MQTT Broker ───────────────────────────────────────────────
#define MQTT_BROKER "YOUR_MQTT_BROKER_IP"
#define MQTT_PORT 1883
#define MQTT_USERNAME "YOUR_MQTT_USERNAME"
#define MQTT_PASSWORD "YOUR_MQTT_PASSWORD"

// ── OTA (Over-the-Air) Updates ────────────────────────────────
#define OTA_PASSWORD "YOUR_OTA_PASSWORD"

## 5.3 config.h

This file contains all project constants, pin definitions, timing intervals, and MQTT topic configuration. Edit these values to customize the project for your environment.

// ════════════════════════════════════════════════════════════════
// config.h — Project Configuration Constants
// ════════════════════════════════════════════════════════════════

#pragma once

// ── Device Identity ───────────────────────────────────────────
#define DEVICE_NAME "esp32_multi_sensor"
#define DEVICE_FRIENDLY_NAME "ESP32 Multi-Sensor Station"
#define SW_VERSION "1.0.0"

// ── MQTT Topics ───────────────────────────────────────────────
#define MQTT_TOPIC_PREFIX "home/esp32_multi_sensor"
#define MQTT_DISCOVERY_PREFIX "homeassistant"
#define AVAILABILITY_TOPIC MQTT_TOPIC_PREFIX "/availability"
#define STATE_TOPIC MQTT_TOPIC_PREFIX "/state"
#define COMMAND_TOPIC MQTT_TOPIC_PREFIX "/command"

// ── Timing Intervals (milliseconds) ──────────────────────────
#define SENSOR_READ_INTERVAL 30000 // 30 seconds between sensor reads
#define MQTT_RECONNECT_INTERVAL 5000 // 5 seconds between MQTT retries
#define WIFI_RECONNECT_INTERVAL 10000 // 10 seconds between WiFi retries

// ── GPIO Pin Assignments ─────────────────────────────────────
#define PIR_PIN 27 // HC-SR501 motion sensor output
#define LDR_PIN 34 // LDR voltage divider (ADC1_CH6)
#define STATUS_LED_PIN 2 // Onboard LED (active HIGH)

// ── I2C / Sensor Configuration ───────────────────────────────
#define BME280_I2C_ADDR 0x76 // Default BME280 address (alt: 0x77)

// ── Light Sensor Thresholds ──────────────────────────────────
#define LDR_DARK_THRESHOLD 500 // ADC value below which "dark" is reported

═

═

═

═

═

═

PAGE BREAK

═

═

═

═

═

═

# 6. Complete Source Code — main.cpp

Below is the complete, compilable source code for the ESP32 Multi-Sensor Station. Copy this file to src/main.cpp in your PlatformIO project.

/***********************************************************
* ESP32 Multi-Sensor Station
* PlatformIO + Arduino Framework
*
* Reads BME280 (temp/humidity/pressure), PIR motion,
* and LDR ambient light. Publishes to Home Assistant
* via MQTT with Auto-Discovery.
*
* Version: 1.0.0
* License: MIT
* Date: May 2026
***********************************************************/

#include <WiFi.h>
#include <PubSubClient.h>
#include <Wire.h>
#include <Adafruit_Sensor.h>
#include <Adafruit_BME280.h>
#include <ArduinoJson.h>
#include <ArduinoOTA.h>

#include "config.h"
#include "secrets.h"

// ════════════════════════════════════════════════════════════
// GLOBAL OBJECTS
// ════════════════════════════════════════════════════════════

WiFiClient espClient;
PubSubClient mqttClient(espClient);
Adafruit_BME280 bme;

// ════════════════════════════════════════════════════════════
// TIMING VARIABLES
// ════════════════════════════════════════════════════════════

unsigned long lastSensorRead = 0;
unsigned long lastMqttReconnect = 0;
unsigned long lastWifiReconnect = 0;

// ════════════════════════════════════════════════════════════
// SENSOR STATE VARIABLES
// ════════════════════════════════════════════════════════════

float lastTemperature = 0.0;
float lastHumidity = 0.0;
float lastPressure = 0.0;
int lastLightLevel = 0;
bool lastMotionState = false;

// ════════════════════════════════════════════════════════════
// CONNECTION STATE
// ════════════════════════════════════════════════════════════

bool discoveryConfigSent = false;
int wifiReconnectAttempts = 0;
bool bmeInitialized = false;

// ════════════════════════════════════════════════════════════
// FUNCTION: setupWiFi()
// Connects to WiFi with exponential backoff on failure.
// ════════════════════════════════════════════════════════════

void setupWiFi() {
Serial.println();
Serial.print("[WiFi] Connecting to ");
Serial.println(WIFI_SSID);

WiFi.mode(WIFI_STA);
WiFi.begin(WIFI_SSID, WIFI_PASSWORD);

// Wait for connection with timeout
int attempts = 0;
while (WiFi.status() != WL_CONNECTED && attempts < 40) {
delay(500);
Serial.print(".");
attempts++;
}

if (WiFi.status() == WL_CONNECTED) {
wifiReconnectAttempts = 0;
Serial.println();
Serial.println("[WiFi] Connected!");
Serial.print("[WiFi] IP Address: ");
Serial.println(WiFi.localIP());
} else {
// Calculate exponential backoff delay (max 30 seconds)
int backoffDelay = min(1000 * (1 << wifiReconnectAttempts), 30000);
wifiReconnectAttempts++;
Serial.println();
Serial.print("[WiFi] Connection failed. Retry in ");
Serial.print(backoffDelay / 1000);
Serial.println("s");
delay(backoffDelay);
}
}

// ════════════════════════════════════════════════════════════
// FUNCTION: setupOTA()
// Configures Over-the-Air update capability.
// ════════════════════════════════════════════════════════════

void setupOTA() {
ArduinoOTA.setHostname(DEVICE_NAME);
ArduinoOTA.setPassword(OTA_PASSWORD);

ArduinoOTA.onStart([]() {
String type;
if (ArduinoOTA.getCommand() == U_FLASH) {
type = "sketch";
} else {
type = "filesystem";
}
Serial.println("[OTA] Start updating " + type);
});

ArduinoOTA.onEnd([]() {
Serial.println("\n[OTA] Update complete!");
});

ArduinoOTA.onProgress([](unsigned int progress, unsigned int total) {
Serial.printf("[OTA] Progress: %u%%\r", (progress / (total / 100)));
});

ArduinoOTA.onError([](ota_error_t error) {
Serial.printf("[OTA] Error[%u]: ", error);
if (error == OTA_AUTH_ERROR) Serial.println("Auth Failed");
else if (error == OTA_BEGIN_ERROR) Serial.println("Begin Failed");
else if (error == OTA_CONNECT_ERROR) Serial.println("Connect Failed");
else if (error == OTA_RECEIVE_ERROR) Serial.println("Receive Failed");
else if (error == OTA_END_ERROR) Serial.println("End Failed");
});

ArduinoOTA.begin();
Serial.println("[OTA] Ready");
}

// ════════════════════════════════════════════════════════════
// FUNCTION: mqttCallback()
// Handles incoming MQTT messages (for future command support).
// ════════════════════════════════════════════════════════════

void mqttCallback(char* topic, byte* payload, unsigned int length) {
Serial.print("[MQTT] Message received on topic: ");
Serial.println(topic);

// Convert payload to string
String message;
for (unsigned int i = 0; i < length; i++) {
message += (char)payload[i];
}
Serial.print("[MQTT] Payload: ");
Serial.println(message);

// Future: Handle commands here (e.g., change read interval)
}

// ════════════════════════════════════════════════════════════
// FUNCTION: sendDiscoveryConfig()
// Publishes MQTT Auto-Discovery configuration for each
// sensor entity so Home Assistant creates them automatically.
// ════════════════════════════════════════════════════════════

void sendDiscoveryConfig() {
Serial.println("[Discovery] Sending Auto-Discovery configs...");

// ── Shared device block (reused for every entity) ─────
// We build it fresh in each payload to keep ArduinoJson
// memory management simple.

// Buffer for serialized JSON
char configBuffer[768];

// ────────────────────────────────────────────────────────
// 1. TEMPERATURE SENSOR
// ────────────────────────────────────────────────────────
{
JsonDocument doc;
doc["name"] = "Temperature";
doc["unique_id"] = DEVICE_NAME "_temperature";
doc["state_topic"] = STATE_TOPIC;
doc["value_template"] = "{{ value_json.temperature }}";
doc["device_class"] = "temperature";
doc["unit_of_measurement"] = "°C";
doc["availability_topic"] = AVAILABILITY_TOPIC;
doc["payload_available"] = "online";
doc["payload_not_available"] = "offline";

JsonObject device = doc["device"].to<JsonObject>();
JsonArray ids = device["identifiers"].to<JsonArray>();
ids.add(DEVICE_NAME);
device["name"] = DEVICE_FRIENDLY_NAME;
device["manufacturer"] = "DIY";
device["model"] = "ESP32 Multi-Sensor";
device["sw_version"] = SW_VERSION;

serializeJson(doc, configBuffer);
mqttClient.publish(
MQTT_DISCOVERY_PREFIX "/sensor/" DEVICE_NAME "/temperature/config",
configBuffer, true // retained
);
Serial.println("[Discovery] ✓ Temperature sensor registered");
}

// ────────────────────────────────────────────────────────
// 2. HUMIDITY SENSOR
// ────────────────────────────────────────────────────────
{
JsonDocument doc;
doc["name"] = "Humidity";
doc["unique_id"] = DEVICE_NAME "_humidity";
doc["state_topic"] = STATE_TOPIC;
doc["value_template"] = "{{ value_json.humidity }}";
doc["device_class"] = "humidity";
doc["unit_of_measurement"] = "%";
doc["availability_topic"] = AVAILABILITY_TOPIC;
doc["payload_available"] = "online";
doc["payload_not_available"] = "offline";

JsonObject device = doc["device"].to<JsonObject>();
JsonArray ids = device["identifiers"].to<JsonArray>();
ids.add(DEVICE_NAME);
device["name"] = DEVICE_FRIENDLY_NAME;
device["manufacturer"] = "DIY";
device["model"] = "ESP32 Multi-Sensor";
device["sw_version"] = SW_VERSION;

serializeJson(doc, configBuffer);
mqttClient.publish(
MQTT_DISCOVERY_PREFIX "/sensor/" DEVICE_NAME "/humidity/config",
configBuffer, true
);
Serial.println("[Discovery] ✓ Humidity sensor registered");
}

// ────────────────────────────────────────────────────────
// 3. PRESSURE SENSOR
// ────────────────────────────────────────────────────────
{
JsonDocument doc;
doc["name"] = "Pressure";
doc["unique_id"] = DEVICE_NAME "_pressure";
doc["state_topic"] = STATE_TOPIC;
doc["value_template"] = "{{ value_json.pressure }}";
doc["device_class"] = "atmospheric_pressure";
doc["unit_of_measurement"] = "hPa";
doc["availability_topic"] = AVAILABILITY_TOPIC;
doc["payload_available"] = "online";
doc["payload_not_available"] = "offline";

JsonObject device = doc["device"].to<JsonObject>();
JsonArray ids = device["identifiers"].to<JsonArray>();
ids.add(DEVICE_NAME);
device["name"] = DEVICE_FRIENDLY_NAME;
device["manufacturer"] = "DIY";
device["model"] = "ESP32 Multi-Sensor";
device["sw_version"] = SW_VERSION;

serializeJson(doc, configBuffer);
mqttClient.publish(
MQTT_DISCOVERY_PREFIX "/sensor/" DEVICE_NAME "/pressure/config",
configBuffer, true
);
Serial.println("[Discovery] ✓ Pressure sensor registered");
}

// ────────────────────────────────────────────────────────
// 4. LIGHT LEVEL SENSOR
// ────────────────────────────────────────────────────────
{
JsonDocument doc;
doc["name"] = "Light Level";
doc["unique_id"] = DEVICE_NAME "_light";
doc["state_topic"] = STATE_TOPIC;
doc["value_template"] = "{{ value_json.light }}";
doc["device_class"] = "illuminance";
doc["unit_of_measurement"] = "lx";
doc["availability_topic"] = AVAILABILITY_TOPIC;
doc["payload_available"] = "online";
doc["payload_not_available"] = "offline";

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

serializeJson(doc, configBuffer);
mqttClient.publish(
MQTT_DISCOVERY_PREFIX "/sensor/" DEVICE_NAME "/light/config",
configBuffer, true
);
Serial.println("[Discovery] ✓ Light level sensor registered");
}

// ────────────────────────────────────────────────────────
// 5. MOTION BINARY SENSOR
// ────────────────────────────────────────────────────────
{
JsonDocument doc;
doc["name"] = "Motion";
doc["unique_id"] = DEVICE_NAME "_motion";
doc["state_topic"] = STATE_TOPIC;
doc["value_template"] = "{{ value_json.motion }}";
doc["device_class"] = "motion";
doc["payload_on"] = "ON";
doc["payload_off"] = "OFF";
doc["availability_topic"] = AVAILABILITY_TOPIC;
doc["payload_available"] = "online";
doc["payload_not_available"] = "offline";

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

serializeJson(doc, configBuffer);
mqttClient.publish(
MQTT_DISCOVERY_PREFIX "/binary_sensor/" DEVICE_NAME "/motion/config",
configBuffer, true
);
Serial.println("[Discovery] ✓ Motion binary sensor registered");
}

discoveryConfigSent = true;
Serial.println("[Discovery] All entities registered with Home Assistant.");
}

// ════════════════════════════════════════════════════════════
// FUNCTION: reconnectMQTT()
// Attempts to connect to the MQTT broker. Non-blocking with
// interval-based retry. Sets LWT for availability tracking.
// ════════════════════════════════════════════════════════════

void reconnectMQTT() {
if (mqttClient.connected()) return;

unsigned long now = millis();
if (now - lastMqttReconnect < MQTT_RECONNECT_INTERVAL) return;
lastMqttReconnect = now;

Serial.print("[MQTT] Attempting connection to ");
Serial.print(MQTT_BROKER);
Serial.print(":");
Serial.print(MQTT_PORT);
Serial.println("...");

// Connect with LWT (Last Will and Testament)
// If this client disconnects unexpectedly, the broker
// will publish "offline" to the availability topic.
if (mqttClient.connect(
DEVICE_NAME, // Client ID
MQTT_USERNAME, // Username
MQTT_PASSWORD, // Password
AVAILABILITY_TOPIC, // LWT topic
1, // LWT QoS
true, // LWT retain
"offline" // LWT message
)) {

Serial.println("[MQTT] Connected!");

// Publish "online" to availability topic
mqttClient.publish(AVAILABILITY_TOPIC, "online", true);

// Subscribe to command topic for future use
mqttClient.subscribe(COMMAND_TOPIC);
Serial.print("[MQTT] Subscribed to: ");
Serial.println(COMMAND_TOPIC);

// Send discovery config on first connection
if (!discoveryConfigSent) {
sendDiscoveryConfig();
}

} else {
Serial.print("[MQTT] Connection failed, rc=");
Serial.print(mqttClient.state());
Serial.print(" — retrying in ");
Serial.print(MQTT_RECONNECT_INTERVAL / 1000);
Serial.println("s");
}
}

// ════════════════════════════════════════════════════════════
// FUNCTION: readAndPublishSensors()
// Reads all sensors, builds a JSON payload, and publishes
// it to the MQTT state topic.
// ════════════════════════════════════════════════════════════

void readAndPublishSensors() {
// ── Read BME280 ───────────────────────────────────────
if (bmeInitialized) {
lastTemperature = bme.readTemperature(); // °C
lastHumidity = bme.readHumidity(); // %
lastPressure = bme.readPressure() / 100.0F; // Pa → hPa
} else {
lastTemperature = -99.0;
lastHumidity = -99.0;
lastPressure = -99.0;
}

// ── Read LDR (Analog) ─────────────────────────────────
int rawADC = analogRead(LDR_PIN);
// Map 12-bit ADC (0–4095) to approximate lux (0–1000)
// This is a rough linear mapping; calibrate for accuracy
lastLightLevel = map(rawADC, 0, 4095, 0, 1000);

// ── Read PIR (Digital) ────────────────────────────────
lastMotionState = digitalRead(PIR_PIN) == HIGH;

// ── Build JSON Payload ────────────────────────────────
JsonDocument doc;
doc["temperature"] = serialized(String(lastTemperature, 2));
doc["humidity"] = serialized(String(lastHumidity, 1));
doc["pressure"] = serialized(String(lastPressure, 2));
doc["light"] = lastLightLevel;
doc["motion"] = lastMotionState ? "ON" : "OFF";

char payload[256];
serializeJson(doc, payload);

// ── Publish to MQTT ───────────────────────────────────
if (mqttClient.publish(STATE_TOPIC, payload)) {
Serial.print("[Sensors] Published: ");
Serial.println(payload);
} else {
Serial.println("[Sensors] Publish FAILED");
}

// ── Blink status LED briefly ──────────────────────────
digitalWrite(STATUS_LED_PIN, HIGH);
delay(50);
digitalWrite(STATUS_LED_PIN, LOW);
}

// ════════════════════════════════════════════════════════════
// FUNCTION: setup()
// One-time initialization: serial, pins, sensors, WiFi,
// MQTT, and OTA.
// ════════════════════════════════════════════════════════════

void setup() {
// ── Serial ────────────────────────────────────────────
Serial.begin(115200);
delay(1000);

Serial.println();
Serial.println("╔══════════════════════════════════════════╗");
Serial.println("║ ESP32 Multi-Sensor Station v" SW_VERSION " ║");
Serial.println("║ MQTT Auto-Discovery for Home Asst. ║");
Serial.println("╚══════════════════════════════════════════╝");
Serial.println();

// ── GPIO Setup ────────────────────────────────────────
pinMode(PIR_PIN, INPUT);
pinMode(LDR_PIN, INPUT);
pinMode(STATUS_LED_PIN, OUTPUT);
digitalWrite(STATUS_LED_PIN, LOW);

// ── I2C & BME280 ──────────────────────────────────────
Wire.begin(); // Default SDA=21, SCL=22

Serial.print("[BME280] Initializing at address 0x");
Serial.print(BME280_I2C_ADDR, HEX);
Serial.println("...");

if (bme.begin(BME280_I2C_ADDR)) {
bmeInitialized = true;
Serial.println("[BME280] Sensor found!");
} else {
// Try alternate address
Serial.println("[BME280] Not found at primary address.");
Serial.println("[BME280] Trying alternate address 0x77...");
if (bme.begin(0x77)) {
bmeInitialized = true;
Serial.println("[BME280] Sensor found at 0x77!");
} else {
bmeInitialized = false;
Serial.println("[BME280] ERROR: Sensor not detected!");
Serial.println("[BME280] Check wiring and I2C address.");
}
}

// ── WiFi ──────────────────────────────────────────────
setupWiFi();

// ── MQTT ──────────────────────────────────────────────
mqttClient.setServer(MQTT_BROKER, MQTT_PORT);
mqttClient.setCallback(mqttCallback);
mqttClient.setBufferSize(768); // Larger buffer for discovery payloads

// ── OTA ───────────────────────────────────────────────
setupOTA();

Serial.println();
Serial.println("[Setup] Initialization complete. Entering main loop.");
Serial.println();
}

// ════════════════════════════════════════════════════════════
// FUNCTION: loop()
// Main loop: handles OTA, WiFi/MQTT reconnection, and
// periodic sensor reads.
// ════════════════════════════════════════════════════════════

void loop() {
// ── Handle OTA updates ────────────────────────────────
ArduinoOTA.handle();

// ── WiFi Reconnection ─────────────────────────────────
if (WiFi.status() != WL_CONNECTED) {
unsigned long now = millis();
if (now - lastWifiReconnect >= WIFI_RECONNECT_INTERVAL) {
lastWifiReconnect = now;
Serial.println("[WiFi] Connection lost. Reconnecting...");
setupWiFi();
}
return; // Skip MQTT and sensors until WiFi is back
}

// ── MQTT Reconnection ─────────────────────────────────
if (!mqttClient.connected()) {
reconnectMQTT();
}

// ── MQTT Client Loop ──────────────────────────────────
mqttClient.loop();

// ── Periodic Sensor Read ──────────────────────────────
unsigned long now = millis();
if (now - lastSensorRead >= SENSOR_READ_INTERVAL) {
lastSensorRead = now;
if (mqttClient.connected()) {
readAndPublishSensors();
}
}

// Small yield to prevent watchdog reset
delay(10);
}

Note

The MQTT client buffer size is increased to 768 bytes via setBufferSize(768) to accommodate the Auto-Discovery JSON payloads. The default PubSubClient buffer of 256 bytes is too small for discovery messages that include the full device block.

═

═

═

═

═

═

PAGE BREAK

═

═

═

═

═

═

# 7. MQTT Auto-Discovery Deep Dive

## 7.1 What is MQTT Auto-Discovery?

Home Assistant includes a powerful feature called MQTT Auto-Discovery. When enabled, Home Assistant continuously monitors a designated MQTT topic prefix (by default, homeassistant/) for configuration messages. When a properly formatted JSON payload appears on a config topic under that prefix, Home Assistant automatically creates the corresponding sensor, switch, light, or other entity—no YAML editing required.

This is often called “zero-config” integration because the device itself tells Home Assistant what it is, what data it provides, and how to interpret that data. You flash your ESP32 once, and the sensors simply appear in the Home Assistant UI.

The discovery mechanism is designed to be idempotent: sending the same configuration message multiple times has no adverse effect. This means your ESP32 can safely re-send its discovery configuration every time it reconnects to the MQTT broker.

## 7.2 Discovery Topic Format

Every discovery message must be published to a topic that follows this strict structure:

<discovery_prefix>/<component>/<node_id>/<object_id>/config

Segment | Description | Example
discovery_prefix | The root topic Home Assistant monitors. Default is homeassistant. | homeassistant
component | The Home Assistant platform type: sensor, binary_sensor, switch, light, fan, cover, etc. | sensor
node_id | A unique identifier for the device or node. Groups entities logically. | esp32_multi_sensor
object_id | A unique identifier for this specific entity on the device. | temperature
/config | The fixed suffix that tells Home Assistant “this is a discovery message.” | —

Complete example topic for our temperature sensor:

homeassistant/sensor/esp32_multi_sensor/temperature/config

## 7.3 Discovery Payload Anatomy

The payload published to the config topic is a JSON object that describes the entity in full. Below is a complete, annotated example for the temperature sensor:

{
"name": "Temperature",
"unique_id": "esp32_multi_sensor_temperature",
"state_topic": "home/esp32_multi_sensor/state",
"value_template": "{{ value_json.temperature }}",
"device_class": "temperature",
"unit_of_measurement": "°C",
"availability_topic": "home/esp32_multi_sensor/availability",
"payload_available": "online",
"payload_not_available": "offline",
"device": {
"identifiers": ["esp32_multi_sensor"],
"name": "ESP32 Multi-Sensor Station",
"manufacturer": "DIY",
"model": "ESP32 Multi-Sensor",
"sw_version": "1.0.0"
}
}

The following table explains every field in the discovery payload:

Field | Required | Purpose
name | Yes | The display name shown in the Home Assistant UI.
unique_id | Recommended | A globally unique identifier. Enables UI customization and entity registry persistence across restarts.
state_topic | Yes | The MQTT topic where the device publishes its sensor data.
value_template | Depends | A Jinja2 template that extracts the specific value from the JSON payload on state_topic.
device_class | Recommended | Tells HA the type of data (temperature, humidity, etc.) so it can apply the correct icon and formatting.
unit_of_measurement | Recommended | The unit displayed alongside the value (°C, %, hPa, lx).
availability_topic | Optional | The MQTT topic for online/offline status tracking.
payload_available | Optional | The payload value that means “the device is online” (default: “online”).
payload_not_available | Optional | The payload value that means “the device is offline” (default: “offline”).
device | Recommended | A nested object that groups multiple entities under one device in the HA device registry.

## 7.4 The Device Block

The device object in the discovery payload is what makes the Home Assistant UI truly organized. When multiple entities (temperature, humidity, pressure, light, motion) all share the same identifiers value, Home Assistant groups them together on a single device page.

Device Field | Purpose | Example Value
identifiers | Array of unique IDs for this device. Entities sharing an identifier are grouped together. | ["esp32_multi_sensor"]
name | Human-readable name displayed in the device registry. | "ESP32 Multi-Sensor Station"
manufacturer | Displayed as the device manufacturer. | "DIY"
model | Displayed as the device model. | "ESP32 Multi-Sensor"
sw_version | Software/firmware version for tracking updates. | "1.0.0"
configuration_url | (Optional) A URL for the device’s web config page, if available. | "http://192.168.1.x"

## 7.5 Value Templates (Jinja2)

Because our ESP32 publishes one JSON object containing all sensor readings to a single state topic, each entity in Home Assistant needs a way to extract just its own value from that combined payload. This is accomplished with the value_template field, which uses Jinja2 template syntax.

When Home Assistant receives a message on the state_topic, it passes the raw payload through the Jinja2 template engine. The template extracts the relevant value:

Entity | Value Template | Extracts From JSON
Temperature | {{ value_json.temperature }} | "temperature": 23.45
Humidity | {{ value_json.humidity }} | "humidity": 58.2
Pressure | {{ value_json.pressure }} | "pressure": 1013.25
Light Level | {{ value_json.light }} | "light": 450
Motion | {{ value_json.motion }} | "motion": "ON"

This single-topic, multi-value approach is efficient because it reduces the number of MQTT publishes per read cycle from five to one.

## 7.6 Availability & LWT (Last Will and Testament)

MQTT includes a mechanism called Last Will and Testament (LWT) that provides automatic offline detection. Here is how it works in this project:

1. On connect: When the ESP32 connects to the MQTT broker, it registers a “last will” message as part of the CONNECT packet. The will says: “If I disconnect unexpectedly, please publish the payload offline to the topic home/esp32_multi_sensor/availability with the retain flag set.”
2. Immediately after connecting: The ESP32 publishes online to the same availability topic (retained). This tells Home Assistant the device is alive.
3. On unexpected disconnect: If the ESP32 loses power, crashes, or loses network connectivity, the MQTT broker detects the broken TCP connection and automatically publishes the LWT message (offline) on the device’s behalf.
4. Home Assistant reacts: Because each entity’s discovery config includes availability_topic, Home Assistant marks all five entities as “Unavailable” in the UI. When the ESP32 reconnects and publishes online, the entities become available again.

The retain flag is critical here: it ensures that even if Home Assistant restarts after the ESP32 has gone offline, it will still see the last retained availability message and correctly show the device as unavailable.

## 7.7 Removing Discovered Entities

During development, you may want to remove entities that were previously auto-discovered. To do this, publish an empty (zero-length) payload to the discovery config topic. For example, to remove the temperature sensor:

# Using mosquitto_pub from the command line:
mosquitto_pub -h YOUR_MQTT_BROKER_IP -u YOUR_MQTT_USERNAME -P YOUR_MQTT_PASSWORD \
-t "homeassistant/sensor/esp32_multi_sensor/temperature/config" \
-n -r

# The -n flag sends a zero-length (null) payload
# The -r flag sets the retain bit (clears the retained config)

Home Assistant will immediately remove the entity from its registry. To remove all five entities from this project, repeat the command for each discovery topic listed in Section 11.

═

═

═

═

═

═

PAGE BREAK

═

═

═

═

═

═

# 8. Home Assistant Setup Guide

This section walks you through setting up the Home Assistant side of the integration, from installing the MQTT broker to verifying that your sensor entities appear.

## 8.1 Installing the Mosquitto Broker Add-on

Home Assistant OS and Home Assistant Supervised include an official Mosquitto MQTT broker add-on. Follow these steps to install it:

5. Open your Home Assistant web interface.
6. Navigate to Settings → Add-ons.
7. Click Add-on Store (bottom right).
8. Search for “Mosquitto broker”.
9. Click on the Mosquitto broker add-on, then click Install.
10. After installation completes, click Start.
11. Enable “Start on boot” and optionally “Watchdog” for automatic restart on failure.
12. Check the add-on logs to verify it started successfully.

Tip

If you are running Home Assistant Container or Home Assistant Core, you will need to install Mosquitto separately on your host system or in another container. The configuration steps for the MQTT integration remain the same.

## 8.2 Creating an MQTT User

The Mosquitto add-on authenticates using Home Assistant user accounts. Create a dedicated user for MQTT:

13. Go to Settings → People.
14. Click the Users tab.
15. Click Add User.
16. Enter a display name (e.g., “MQTT User”).
17. Enter a username (e.g., mqtt_user).
18. Set a strong password.
19. Toggle off “Administrator” (this user does not need admin access).
20. Click Create.

Use the username and password you just created as the values for YOUR_MQTT_USERNAME and YOUR_MQTT_PASSWORD in your secrets.h file.

## 8.3 Configuring the MQTT Integration

21. Go to Settings → Devices & Services.
22. Home Assistant should auto-detect the Mosquitto broker and show a notification. Click Configure.
23. If auto-detection does not appear, click Add Integration, search for MQTT, and configure manually:
  - Broker: localhost (or core-mosquitto if using the add-on)
  - Port: 1883
  - Username / Password: the MQTT user you created above
24. Click Submit. The MQTT integration should show as connected.

## 8.4 Verifying Entity Discovery

After flashing the ESP32 firmware and powering on the board:

25. Open the Serial Monitor in PlatformIO (or any terminal at 115200 baud) to confirm the ESP32 connects to WiFi and MQTT, and that all five discovery messages are sent.
26. In Home Assistant, go to Settings → Devices & Services → MQTT.
27. You should see “ESP32 Multi-Sensor Station” listed as a device.
28. Click on the device to see all five entities:
  - Temperature (sensor)
  - Humidity (sensor)
  - Pressure (sensor)
  - Light Level (sensor)
  - Motion (binary sensor)
29. Each entity should display current readings that update every 30 seconds.

Note

If entities do not appear, use a tool like MQTT Explorer to inspect the broker. Verify that retained messages exist on the discovery config topics and that the JSON payloads are well-formed. Common issues include buffer size limitations and incorrect topic prefixes.

## 8.5 Adding Entities to Dashboards

Once entities are discovered, add them to your Lovelace dashboard:

30. Navigate to your dashboard (Overview or a custom dashboard).
31. Click the three-dot menu (top right) and select Edit Dashboard.
32. Click Add Card.
33. For sensor values, choose “Entities” or “Gauge” card. For the motion sensor, a “Mushroom Entity” or standard “Entity” card works well.
34. Search for your entities by name (e.g., “ESP32 Multi-Sensor Temperature”).
35. Configure the card appearance and click Save.

## 8.6 Creating Automations with the Motion Sensor

One of the most practical uses of the PIR motion sensor is triggering automations. Below is an example automation that turns on a light when motion is detected:

# Example automation — add to automations.yaml or create via UI
automation:
- alias: "Motion Light On"
description: "Turn on the hallway light when motion is detected"
trigger:
- platform: state
entity_id: binary_sensor.esp32_multi_sensor_motion
to: "on"
action:
- service: light.turn_on
target:
entity_id: light.your_light_entity
mode: single

- alias: "Motion Light Off"
description: "Turn off the light 5 minutes after motion stops"
trigger:
- platform: state
entity_id: binary_sensor.esp32_multi_sensor_motion
to: "off"
for:
minutes: 5
action:
- service: light.turn_off
target:
entity_id: light.your_light_entity
mode: single

Important

Replace light.your_light_entity with the actual entity ID of the light you want to control. You can find entity IDs under Settings → Devices & Services → Entities.

═

═

═

═

═

═

PAGE BREAK

═

═

═

═

═

═

# 9. .gitignore File

Place this file in the project root to prevent credentials and build artifacts from being committed to version control.

# ════════════════════════════════════════════════════════════════
# .gitignore — ESP32 Multi-Sensor Station
# ════════════════════════════════════════════════════════════════

# PlatformIO build directory
.pio/

# VS Code / PlatformIO IDE settings
.vscode/

# ⚠️ NEVER commit credentials
include/secrets.h

# Compiled binaries and object files
*.o
*.obj
*.elf
*.bin
*.hex
*.map

# OS-generated files
.DS_Store
Thumbs.db

═

═

═

═

═

═

PAGE BREAK

═

═

═

═

═

═

# 10. Troubleshooting & FAQ

The following table covers the most common issues encountered when building and deploying this project, along with their solutions.

Problem | Possible Cause | Solution
BME280 not detected (Serial shows “Sensor not detected”) | Wrong I2C address, loose wiring, or defective module. | Check if your BME280 uses address 0x76 or 0x77 (varies by manufacturer). Run an I2C scanner sketch to verify. Double-check SDA/SCL wiring and ensure 3.3V power.
MQTT connection fails (Serial shows rc=-2 or rc=-4) | Incorrect broker IP, wrong credentials, or Mosquitto not running. | Verify the broker IP address in secrets.h. Confirm Mosquitto is running (check add-on logs). Test credentials with mosquitto_pub from the command line. Ensure firewall allows port 1883.
Entities not appearing in Home Assistant | Discovery prefix mismatch, malformed JSON, or retain flag not set. | Verify MQTT_DISCOVERY_PREFIX matches HA config (default: homeassistant). Use MQTT Explorer to inspect the discovery topics. Ensure the retain flag is true. Increase PubSubClient buffer size if payloads are truncated.
WiFi keeps disconnecting | Weak signal, power supply issues, or incorrect credentials. | Check WiFi signal strength at the ESP32 location. Use a dedicated 5V/1A+ power supply (not a computer USB port). Verify SSID and password. Consider an ESP32 board with an external antenna connector.
PIR sensor always reads HIGH | Sensitivity too high, insufficient warm-up time, or 3.3V power (needs 5V). | The HC-SR501 requires approximately 60 seconds to stabilize after power-on. Adjust the sensitivity potentiometer (turn clockwise to reduce). Ensure VCC is connected to the 5V pin, not 3.3V.
LDR readings are unstable or noisy | Floating ADC input, wrong resistor value, or electrical interference. | Verify the 10kΩ resistor is properly connected in the voltage divider. Add a 100nF ceramic capacitor between GPIO 34 and GND to filter noise. Keep analog wiring short and away from digital lines.
OTA upload fails | Wrong OTA password, different network, or firewall blocking. | Verify OTA_PASSWORD matches in secrets.h and your PlatformIO upload settings. Ensure the computer and ESP32 are on the same network/subnet. Check that your firewall allows UDP traffic on port 3232.
Compile error: “secrets.h not found” | The secrets template has not been copied. | Copy the template from Section 5.2, save it as include/secrets.h, and fill in your credentials.
Sensor values show −99 | BME280 initialization failed. | The firmware reports −99 when the BME280 is not initialized. Check the Serial Monitor for BME280 error messages. Re-check wiring and I2C address.

═

═

═

═

═

═

PAGE BREAK

═

═

═

═

═

═

# 11. MQTT Topic Reference

The following table provides a complete summary of every MQTT topic used by this project. Use this as a quick reference when debugging with MQTT Explorer or configuring additional integrations.

Topic | Direction | Purpose | Payload Format
home/esp32_multi_sensor/state | ESP32 → HA | Combined sensor data (all readings in one message) | JSON object
home/esp32_multi_sensor/availability | ESP32 → HA | Device online/offline status (LWT) | "online" / "offline"
homeassistant/sensor/esp32_multi_sensor/temperature/config | ESP32 → HA | Auto-Discovery config for temperature sensor | JSON (retained)
homeassistant/sensor/esp32_multi_sensor/humidity/config | ESP32 → HA | Auto-Discovery config for humidity sensor | JSON (retained)
homeassistant/sensor/esp32_multi_sensor/pressure/config | ESP32 → HA | Auto-Discovery config for pressure sensor | JSON (retained)
homeassistant/sensor/esp32_multi_sensor/light/config | ESP32 → HA | Auto-Discovery config for light level sensor | JSON (retained)
homeassistant/binary_sensor/esp32_multi_sensor/motion/config | ESP32 → HA | Auto-Discovery config for motion binary sensor | JSON (retained)
home/esp32_multi_sensor/command | HA → ESP32 | Command topic for future remote control features | String (application-defined)

Example state topic payload:

{
"temperature": 23.45,
"humidity": 58.2,
"pressure": 1013.25,
"light": 450,
"motion": "OFF"
}

═

═

═

═

═

═

PAGE BREAK

═

═

═

═

═

═

# 12. Revision History & License

## Revision History

Version | Date | Changes
1.0.0 | May 2026 | Initial release. Full sensor suite (BME280, PIR, LDR), MQTT Auto-Discovery, OTA updates, WiFi reconnection with exponential backoff, LWT availability tracking.

## License

This project is released under the MIT License.

MIT License

Copyright (c) 2026 [Your Name]

Permission is hereby granted, free of charge, to any person obtaining
a copy of this software and associated documentation files (the
"Software"), to deal in the Software without restriction, including
without limitation the rights to use, copy, modify, merge, publish,
distribute, sublicense, and/or sell copies of the Software, and to
permit persons to whom the Software is furnished to do so, subject
to the following conditions:

The above copyright notice and this permission notice shall be
included in all copies or substantial portions of the Software.

THE SOFTWARE IS PROVIDED "AS IS", WITHOUT WARRANTY OF ANY KIND,
EXPRESS OR IMPLIED, INCLUDING BUT NOT LIMITED TO THE WARRANTIES OF
MERCHANTABILITY, FITNESS FOR A PARTICULAR PURPOSE AND
NONINFRINGEMENT. IN NO EVENT SHALL THE AUTHORS OR COPYRIGHT HOLDERS
BE LIABLE FOR ANY CLAIM, DAMAGES OR OTHER LIABILITY, WHETHER IN AN
ACTION OF CONTRACT, TORT OR OTHERWISE, ARISING FROM, OUT OF OR IN
CONNECTION WITH THE SOFTWARE OR THE USE OR OTHER DEALINGS IN THE
SOFTWARE.

ESP32 Multi-Sensor Station — Complete Project Reference
Version 1.0.0 | May 2026 | PlatformIO + Arduino Framework
Home Assistant MQTT Auto-Discovery

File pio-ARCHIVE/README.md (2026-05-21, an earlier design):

# Sentinel ESP32

Sentinel is an ESP32-based multi-sensor node for Home Assistant with MQTT auto-discovery, runtime-tunable detection logic, and a lightweight BLE presence watchlist.

## Current firmware

- Firmware source: `src/main.cpp`
- ESPHome config: `esphome/sentinel.yaml`
- Build system: PlatformIO (`esp32dev`)
- MQTT base: `sentinel/<device_id>/...`
- Runtime config storage: ESP32 NVS (`sentinel_cfg` namespace)

## Features

- BME280 environment telemetry over MQTT
- AM312 PIR motion detection with warmup, debounce, and hold timing
- MAX9814 sound intrusion detection using peak-to-peak sampling
- Reed switch door state reporting
- Home Assistant MQTT auto-discovery
- Runtime configuration through Home Assistant MQTT entities and serial `cfg` commands
- BLE watchlist presence tracking using iBeacon `UUID + major + minor`
- Serial iBeacon enrollment logging with `ble enroll on`

## Primary docs

- `docs/Sentinel_ESP32_Node.md` - firmware overview, build/flash, serial config, BLE enrollment
- `docs/MQTT_Topic_Map.md` - MQTT state, config, and discovery topics
- `docs/Adjustments.MD` - PIR, sound, and BLE watchlist tuning guide
- `docs/Sentinel_Lovelace_Dashboard.md` - Home Assistant dashboard layout, install steps, and troubleshooting view
- `docs/Sentinel_Home_Assistant_Helpers.md` - Home Assistant package for counters, last-event tracking, and mode helpers
- `docs/Sentinel_Full_Project_Reference.md` - high-level hardware, firmware, and integration reference
- `docs/Hardware_Deliverables.md` - hardware package guidance

## Build and flash

```powershell
& "$env:USERPROFILE\.platformio\penv\Scripts\platformio.exe" run -d "d:\Source Code\ESP32\Sent" -e esp32dev
& "$env:USERPROFILE\.platformio\penv\Scripts\platformio.exe" run -d "d:\Source Code\ESP32\Sent" -e esp32dev -t upload --upload-port COM6
```

Adjust `COM6` to the active ESP32 port if needed.

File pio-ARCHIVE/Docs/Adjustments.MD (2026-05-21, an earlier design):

# Sensor Adjustments

This guide covers how to adjust the user-tunable detection features in Sentinel:

- PIR motion on GPIO 27 using the AM312 Mini PIR
- Sound intrusion on GPIO 34 using the MAX9814 microphone board
- BLE beacon watchlist presence tracking

These settings are runtime-configurable, stored in NVS, and survive reboot.

## Where to Adjust

You can adjust settings in either of these ways:

1. Home Assistant MQTT `number` entities
2. Serial `cfg` commands over USB/serial monitor

If you change a value in Home Assistant, the ESP32 applies it immediately and saves it to NVS.

If you change a value over serial, use:

```text
cfg set <key> <value>
cfg save
cfg apply
```

To see the current values:

```text
cfg show
```
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

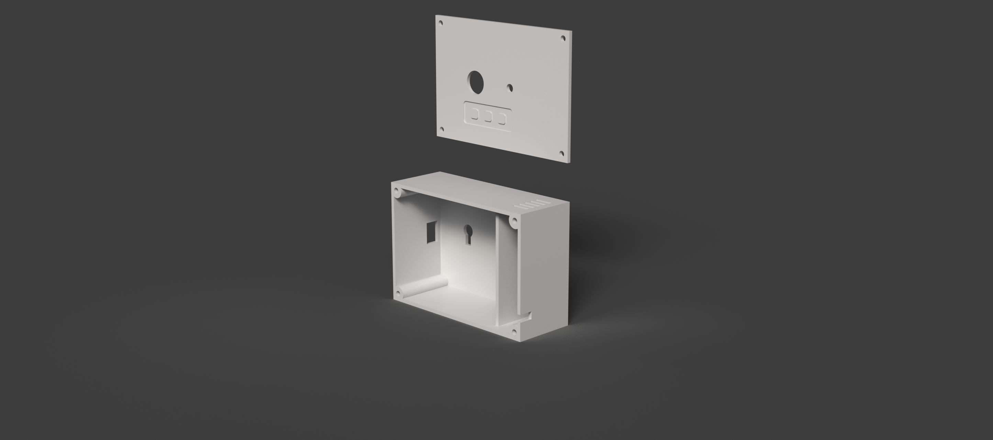
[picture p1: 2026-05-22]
hardware/3D Enclosure/Openscad_LED_Lid_v2_7.png

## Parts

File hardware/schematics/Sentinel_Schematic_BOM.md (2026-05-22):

# Sentinel Schematic BOM And Connector Plan

This file is the build-oriented companion to `Sentinel_ESP32_Node.kicad_sch` and `Sentinel_KiCad_Netlist.net`.

This document remains the electrical reference for the Sentinel design, but the currently recommended physical build path is the existing AITRIP baseplate / expansion kit with Dupont wiring documented in `hardware/Sentinel_Baseplate_Kit_Wiring.md`.

## 1. Reference Designator BOM

| RefDes | Item | Electrical Role | Suggested Footprint / Form |
| :--- | :--- | :--- | :--- |
| **U1** | AITRIP ESP-WROOM-32 / ESP-32S Type-C CH340C host board | Main controller, power source, GPIO host | 30-pin ESP32 DevKit V1 / ESP-32S style board |
| **U2** | BME280 breakout | I2C environmental sensor | 4-pin I2C breakout |
| **U3** | AM312 PIR module | Digital motion sensor | 3-pin module header |
| **U4** | MAX9814 microphone module | Analog sound input | 5-pin module header |
| **S1** | MC-38 reed switch | Door / magnetic contact input | 2-wire external switch |
| **D1** | WS2812 LED, left | External status LED 1 | WS2812B package or intact strip position 1 |
| **D2** | WS2812 LED, center | External status LED 2 | WS2812B package or intact strip position 2 |
| **D3** | WS2812 LED, right | External status LED 3 | WS2812B package or intact strip position 3 |
| **R1** | 330-470 ohm resistor | Series resistor on GPIO25 LED data line | 0805 or leaded equivalent |
| **C1** | 470-1000 uF capacitor | Bulk capacitor across LED 5V and GND | Radial electrolytic or equivalent |

## 2. Connection Landing Table

| RefDes | Pin / Terminal | Connects To | Net / Function |
| :--- | :--- | :--- | :--- |
| **U2** | VCC | U1 `3V3` | `3.3V` |
| **U2** | GND | U1 `GND` | `GND` |
| **U2** | SDA | U1 `GPIO21` | `I2C_SDA` |
| **U2** | SCL | U1 `GPIO22` | `I2C_SCL` |
| **U3** | VCC | U1 `3V3` | `3.3V` |
| **U3** | GND | U1 `GND` | `GND` |
| **U3** | OUT | U1 `GPIO27` | `PIR_DATA` |
| **U4** | VCC | U1 `3V3` | `3.3V` |
| **U4** | GND | U1 `GND` | `GND` |
| **U4** | OUT | U1 `GPIO34` | `MIC_ANALOG` |
| **S1** | Terminal 1 | U1 `GPIO32` | `REED_SIGNAL` |
| **S1** | Terminal 2 | U1 `GND` | `GND` |
| **R1** | Pin 1 | U1 `GPIO25` | `LED_DATA` |
| **R1** | Pin 2 | D1 `DIN` | `LED_DATA_IN` |
| **D1** | VDD | U1 `5V/VIN` | `5V_LED` |
| **D1** | GND | U1 `GND` | `GND` |
| **D1** | DOUT | D2 `DIN` | `LED1_TO_LED2` |
| **D2** | VDD | U1 `5V/VIN` | `5V_LED` |
| **D2** | GND | U1 `GND` | `GND` |
| **D2** | DOUT | D3 `DIN` | `LED2_TO_LED3` |
| **D3** | VDD | U1 `5V/VIN` | `5V_LED` |
| **D3** | GND | U1 `GND` | `GND` |
| **C1** | Positive | U1 `5V/VIN` | `5V_LED` |
| **C1** | Negative | U1 `GND` | `GND` |

## 3. Harness And Build Notes

- The confirmed ESP32 host is a 30-pin ESP32 DevKit V1 / ESP-32S style board, not a 38-pin DevKitC layout.
- The board headers are labeled `3V3 GND D15 D2 D4 RX2 TX2 D5 D18 D19 D21 RX0 TX0 D22 D23` on the top row and `EN VP VN D34 D35 D32 D33 D25 D26 D27 D14 D12 D13 GND VIN` on the bottom row when viewed with antenna left and USB right.
- The external status indicator is one intact horizontal 3-LED strip in the enclosure `v2_7` layout.
- Preserve left / center / right LED order as `D1`, `D2`, `D3` to match the enclosure window order.
- Keep `R1` physically close to LED 1 data input.
- Keep `C1` physically close to the LED power entry.
- Sensors remain on `3V3`; the WS2812 chain remains on `5V/VIN`.
- All grounds must be common.

## 4. Firmware-Relevant Mapping

- `GPIO21` / `GPIO22`: BME280 I2C
- `GPIO27`: PIR digital output
- `GPIO34`: MAX9814 analog output
- `GPIO32`: reed switch input
- `GPIO25`: external 3-pixel status LED data
- `GPIO2`: onboard ESP32 status LED

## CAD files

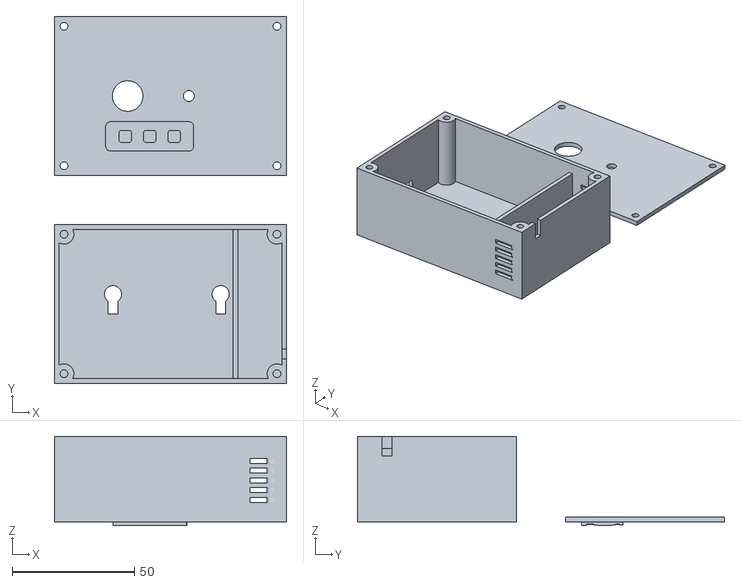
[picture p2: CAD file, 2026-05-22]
hardware/3D Enclosure/Openscad_LED_Lid_v2_7_barholder.stl
95.0 x 150.0 x 36.5

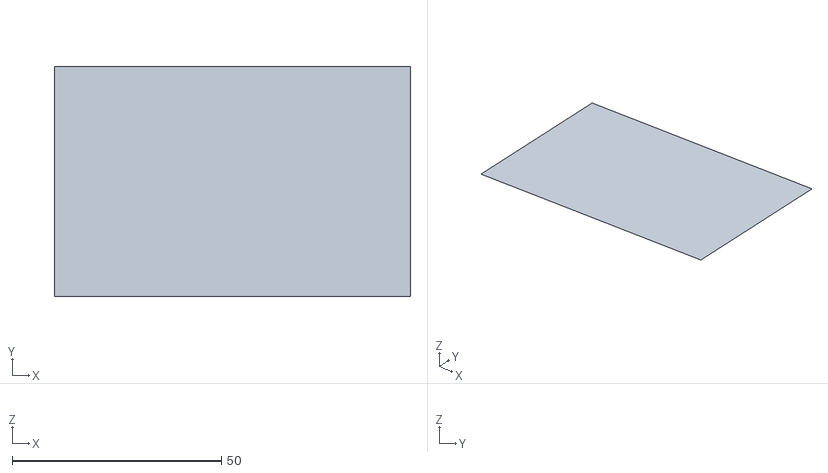
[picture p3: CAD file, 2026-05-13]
hardware/3D Enclosure/Sentinel_Enclosure_Guide.stl
85.0 x 55.0 x 0

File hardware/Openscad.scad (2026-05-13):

// Sentinel ESP32 Node Enclosure v2.2
// FINAL VERSION: Includes BME Vents, Mic Port, and M3 Pillars

$fn = 64;
wall = 2.0;
length = 95; 
width = 65;  
height = 35;
screw_d = 3.2; 
pillar_size = 8;

module base() {
    difference() {
        cube([length, width, height]);
        translate([wall, wall, wall]) 
            cube([length-wall*2, width-wall*2, height]);
        
        // --- NEW: BME280 ISOLATION VENTS ---
        // Side vents to allow cross-flow air into the sensor chamber
        for(i=[0:4]) {
            translate([length-15, width-wall-1, 8 + i*4]) cube([10, wall+2, 2]);
            translate([length-15, -1, 8 + i*4]) cube([10, wall+2, 2]);
        }

        // USB & Reed Switch Cutouts
        translate([-1, width/2-6, wall+2]) cube([wall+2, 12, 8]);
        translate([length-wall-1, 10, height-8]) cube([wall+2, 4, 10]);
    }
    
    // Screw Pillars
    for(x=[pillar_size/2, length-pillar_size/2])
        for(y=[pillar_size/2, width-pillar_size/2])
            translate([x, y, wall]) difference() {
                cylinder(h=height-wall, d=pillar_size);
                cylinder(h=height, d=screw_d);
            }

    // --- REINFORCED BAFFLE WALL ---
    // Physical barrier to block heat from ESP32 reaching BME280
    translate([length-22, wall, wall]) cube([2, width-wall*2, height-wall-5]);
}

module lid() {
    translate([0, width + 20, 0]) {
        difference() {
            cube([length, width, wall]);
            
            // Lid Screw Holes
            translate([pillar_size/2, pillar_size/2, -1]) cylinder(h=wall+2, d=screw_d);
            translate([length-pillar_size/2, pillar_size/2, -1]) cylinder(h=wall+2, d=screw_d);
            translate([pillar_size/2, width-pillar_size/2, -1]) cylinder(h=wall+2, d=screw_d);
            translate([length-pillar_size/2, width-pillar_size/2, -1]) cylinder(h=wall+2, d=screw_d);
            
            // PIR Port
            translate([30, width/2, -1]) cylinder(h=wall+2, d=12.5); 
            
            // --- NEW: MAX9814 ACOUSTIC PORT ---
            // 4.5mm hole with a 1mm recessed chamfer for better sound pickup
            translate([55, width/2, -1]) cylinder(h=wall+2, d=4.5);
        }
    }
}

base();
lid();

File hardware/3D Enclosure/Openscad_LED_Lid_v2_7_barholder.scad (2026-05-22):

// Sentinel ESP32 Node Enclosure v2.7 Horizontal Bar Holder Variant
// Purpose:
// - visibly match one intact 3-LED horizontal strip
// - keep the LED bar away from the PIR hole by lowering it
// - keep wall-mount features
// - keep the original screw holes, PIR port, mic port, vents, and BME divider intact

$fn = 64;
wall = 2.0;
length = 95;
width = 65;
height = 35;
screw_d = 3.2;
pillar_size = 8;

// Preview helpers
show_led_preview_labels = false;
label_height = 0.8;
label_size = 4;

// LED bar layout
// Intact LED strip: 30mm x 15mm with wiring on both left and right ends.
// Lowered to maintain clearer separation from the PIR opening.
led_bar_center = [39, 16];
led_strip_w = 30;
led_strip_h = 15;

// Visible windows for left / center / right LEDs
led_window_w = 5;
led_window_h = 5;
led_window_r = 1;
led_window_centers = [
    [29, 16],
    [39, 16],
    [49, 16]
];

// Holder geometry
led_backing_w = 30;
led_backing_h = 15;
led_backing_depth = 0.8;
led_bottom_ledge_h = 2.0;
led_bottom_ledge_depth = 1.5;
led_side_stop_w = 1.5;
led_side_stop_h = 9;
led_side_stop_depth = 1.3;
led_top_tab_w = 3.5;
led_top_tab_h = 1.5;
led_top_tab_depth = 1.3;
led_top_tab_offsets = [-11, 11];
wire_notch_w = 4;
wire_notch_h = 6;

// Baffles and front bezel
led_baffle_thickness = 2.5;
led_baffle_depth = 1.0;
led_bezel_w = 36;
led_bezel_h = 12;
led_bezel_r = 2;
led_bezel_depth = 0.6;

// Wall mount keyholes in the base back panel.
mount_keyhole_head_d = 7;
mount_keyhole_neck_w = 4;
mount_keyhole_slot_len = 8;
mount_keyhole_x = [24, 68];
mount_keyhole_y = width / 2;

module rounded_rect_2d(w, h, r) {
    hull() {
        translate([-(w/2-r), -(h/2-r)]) circle(r=r);
        translate([ (w/2-r), -(h/2-r)]) circle(r=r);
        translate([-(w/2-r),  (h/2-r)]) circle(r=r);
        translate([ (w/2-r),  (h/2-r)]) circle(r=r);
    }
}

module keyhole_2d(head_d, neck_w, slot_len) {
    union() {
        translate([0, slot_len/2]) circle(d=head_d);
        translate([-neck_w/2, -slot_len/2]) square([neck_w, slot_len]);
    }
}

module led_window_cutouts() {
    for (center = led_window_centers) {
        translate([center[0], center[1], -1])
            linear_extrude(height=wall + 2)
                rounded_rect_2d(led_window_w, led_window_h, led_window_r);
    }
}

module led_diffusers() {
    translate([0, width + 20, 0]) {
        for (center = led_window_centers) {
            translate([center[0], center[1], 0])
                linear_extrude(height=wall)
                    rounded_rect_2d(led_window_w, led_window_h, led_window_r);
        }
    }
}

module led_preview_labels() {
    if (show_led_preview_labels) {
        translate([0, width + 20, 0]) {
            color([0.1, 0.7, 1.0, 0.8]) {
                translate([29, 22, wall])
                    linear_extrude(height=label_height)
                        text("L", size=label_size, halign="center", valign="center");
                translate([39, 22, wall])
                    linear_extrude(height=label_height)
                        text("C", size=label_size, halign="center", valign="center");
                translate([49, 22, wall])
                    linear_extrude(height=label_height)
                        text("R", size=label_size, halign="center", valign="center");
            }
        }
    }
}

module base() {
    difference() {
        cube([length, width, height]);
        translate([wall, wall, wall])
            cube([length-wall*2, width-wall*2, height]);

        for (i = [0:4]) {
            translate([length-15, width-wall-1, 8 + i*4]) cube([10, wall+2, 2]);
            translate([length-15, -1, 8 + i*4]) cube([10, wall+2, 2]);
        }

        translate([-1, width/2-6, wall+2]) cube([wall+2, 12, 8]);
        translate([length-wall-1, 10, height-8]) cube([wall+2, 4, 10]);

        for (x = mount_keyhole_x) {
            translate([x, mount_keyhole_y, -1])
                linear_extrude(height=wall + 2)
                    keyhole_2d(mount_keyhole_head_d, mount_keyhole_neck_w, mount_keyhole_slot_len);
        }
    }

    for (x = [pillar_size/2, length-pillar_size/2])
        for (y = [pillar_size/2, width-pillar_size/2])
            translate([x, y, wall]) difference() {
                cylinder(h=height-wall, d=pillar_size);
                cylinder(h=height, d=screw_d);
            }

    translate([length-22, wall, wall]) cube([2, width-wall*2, height-wall-5]);
}

module led_retainer() {
    translate([led_bar_center[0], led_bar_center[1], 0]) {
        // Thin backing shelf for the full strip.
        translate([-(led_backing_w/2), -(led_backing_h/2), -led_backing_depth])
            cube([led_backing_w, led_backing_h, led_backing_depth]);

        // Bottom ledge supports the strip from below.
        translate([-(led_backing_w/2), -(led_backing_h/2) - led_bottom_ledge_h, -led_bottom_ledge_depth])
            cube([led_backing_w, led_bottom_ledge_h, led_bottom_ledge_depth]);

        // Slim side stops centered vertically, leaving top corners visually open.
        translate([-(led_backing_w/2), -(led_side_stop_h/2), -led_side_stop_depth])
            cube([led_side_stop_w, led_side_stop_h, led_side_stop_depth]);
        translate([(led_backing_w/2) - led_side_stop_w, -(led_side_stop_h/2), -led_side_stop_depth])
            cube([led_side_stop_w, led_side_stop_h, led_side_stop_depth]);

        // Small top tabs near the ends hold the strip in place without a full top rail.
        for (x_off = led_top_tab_offsets) {
            translate([x_off - led_top_tab_w/2, (led_backing_h/2) - led_top_tab_h, -led_top_tab_depth])
                cube([led_top_tab_w, led_top_tab_h, led_top_tab_depth]);
        }

        // Wire relief notches at left and right ends of the bar.
        translate([-(led_backing_w/2) - 0.1, -(wire_notch_h/2), -led_side_stop_depth - 0.1])
            cube([wire_notch_w + 0.2, wire_notch_h, led_side_stop_depth + 0.2]);
        translate([(led_backing_w/2) - wire_notch_w + 0.1, -(wire_notch_h/2), -led_side_stop_depth - 0.1])
            cube([wire_notch_w + 0.2, wire_notch_h, led_side_stop_depth + 0.2]);

        // Light baffles between left/center/right windows.
        for (divider_x = [34, 44]) {
            translate([divider_x - led_bar_center[0] - led_baffle_thickness/2, -(led_backing_h/2), -led_baffle_depth])
                cube([led_baffle_thickness, led_backing_h, led_baffle_depth]);
        }
    }
}

module lid_body() {
    translate([0, width + 20, 0]) {
        union() {
            difference() {
                cube([length, width, wall]);

                translate([pillar_size/2, pillar_size/2, -1]) cylinder(h=wall+2, d=screw_d);
                translate([length-pillar_size/2, pillar_size/2, -1]) cylinder(h=wall+2, d=screw_d);
                translate([pillar_size/2, width-pillar_size/2, -1]) cylinder(h=wall+2, d=screw_d);
                translate([length-pillar_size/2, width-pillar_size/2, -1]) cylinder(h=wall+2, d=screw_d);

                translate([30, width/2, -1]) cylinder(h=wall+2, d=12.5);
                translate([55, width/2, -1]) cylinder(h=wall+2, d=4.5);

                // Horizontal bar bezel for the 3-LED strip.
                translate([led_bar_center[0], led_bar_center[1], wall - led_bezel_depth])
                    linear_extrude(height=led_bezel_depth + 0.1)
                        rounded_rect_2d(led_bezel_w, led_bezel_h, led_bezel_r);

                led_window_cutouts();
            }

            led_retainer();
        }
    }
}

base();
lid_body();
led_diffusers();
led_preview_labels();

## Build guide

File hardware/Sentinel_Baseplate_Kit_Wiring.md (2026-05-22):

# Sentinel ESP32 Baseplate Kit Wiring Guide

This guide covers the AITRIP ESP32 30-pin baseplate / expansion board shown in the user-provided photo.

For the current Sentinel build, this baseplate-plus-Dupont approach is the recommended hardware path over the unfinished custom carrier PCB.

## 1. Confirmed ESP32 Board On This Baseplate

The ESP32 board plugged into this kit is the common 30-pin ESP32 DevKit V1 / ESP-32S style board with these header labels:

- Top row, left to right: `3V3`, `GND`, `D15`, `D2`, `D4`, `RX2`, `TX2`, `D5`, `D18`, `D19`, `D21`, `RX0`, `TX0`, `D22`, `D23`
- Bottom row, left to right: `EN`, `VP`, `VN`, `D34`, `D35`, `D32`, `D33`, `D25`, `D26`, `D27`, `D14`, `D12`, `D13`, `GND`, `VIN`

Sentinel uses:

- `D21` for BME280 SDA
- `D22` for BME280 SCL
- `D27` for PIR OUT
- `D34` for MAX9814 OUT
- `D32` for reed switch signal
- `D25` for WS2812 DIN
- `D2` for onboard status LED
- `3V3`, `VIN`, and `GND` for power distribution

### Sentinel-Only Pin Map

Use this as the fast reference when you do not need the full board header listing.

| Sentinel use | ESP32 label | Purpose |
| :--- | :--- | :--- |
| BME280 SDA | `D21` | I2C data |
| BME280 SCL | `D22` | I2C clock |
| PIR output | `D27` | motion input |
| MAX9814 output | `D34` | analog microphone input |
| Reed switch | `D32` | dry-contact input |
| WS2812 data | `D25` | addressable LED data |
| Onboard LED | `D2` | ESP32 status LED |
| Sensor power | `3V3` | regulated 3.3V rail |
| LED power | `VIN` or dedicated `5V` | 5V LED supply |
| Common ground | `GND` | shared return path |

## 2. How The Baseplate Rows Work

The baseplate breaks each ESP32 header pin out to a 3-pin group.

Those 3-pin groups are labeled with:

- `S` = signal
- `V` = supply rail
- `G` = ground

Important detail from the photo:

- The upper bank is silk-labeled `S V G`
- The lower bank is silk-labeled `G V S`

So the row order is mirrored between the two sides. Follow the printed silk on the board itself. Do not assume the same top-to-bottom order on both header banks.

## 3. The Voltage Selector Jumper

The baseplate has a jumper block labeled around:

- `3.3V`
- `V`
- `5V`
- `JUMP`

This jumper selects what voltage appears on the baseplate's `V` row.

### Recommended setting for Sentinel

Set the jumper to `3.3V`.

Reason:

- BME280 should be powered from `3.3V`
- AM312 PIR should be powered from `3.3V`
- MAX9814 should be powered from `3.3V`
- the reed switch does not need a supply rail
- only the external WS2812 strip should use `5V`

If you set the baseplate `V` rail to `5V`, the normal sensor `V` pins on the Dupont rows would also become `5V`, which is not the intended Sentinel wiring.

## 4. Power Inputs And What They Mean

The baseplate photo shows multiple power entry points.

### A. ESP32 USB-C on the dev board

This is the simplest and safest primary power path for Sentinel.

Use it to:

- flash the ESP32
- power the ESP32 itself
- provide normal development power

### B. Barrel jack marked `DC 6.5-16V`

This belongs to the baseplate, not the ESP32 module itself.

Use this only if you deliberately want to power the baseplate from an external DC supply. For the current Sentinel build, this is not the recommended starting path.

### C. Baseplate micro-USB marked `USB5V`

This is another baseplate-side power input. It is also not the recommended starting path for Sentinel when the ESP32 USB-C is already available.

### D. Separate `5V` / `3.3V` breakout headers

The baseplate photo also shows dedicated power breakout headers labeled `5V`, `3.3V`, and `GND` near the lower-right area.

These are the cleanest places to tap dedicated rails when you need a voltage different from the selected `V` rail.

For Sentinel, this matters because:

- sensors want `3.3V`
- WS2812 wants `5V`

## 5. Recommended Power Strategy For Sentinel

Use this power plan:

1. Power the ESP32 through its own USB-C port.
2. Set the baseplate `V` jumper to `3.3V`.
3. Use the normal `S/V/G` rows for the 3.3V sensors.
4. Do not power the WS2812 strip from the baseplate `V` row.
5. Power the WS2812 strip from the dedicated `5V` breakout or from the ESP32 `VIN` pin breakout.
6. Tie WS2812 ground to the same common ground used by the ESP32 and sensors.

Avoid powering the setup from multiple sources at once until the final power plan is intentionally designed.

## 6. Exact Sentinel Wiring On The Baseplate

### BME280

- `SDA` -> `D21` signal pin
- `SCL` -> `D22` signal pin
- `VCC` -> a `V` pin on the baseplate with jumper set to `3.3V`
- `GND` -> a `G` pin on the baseplate

### AM312 PIR

- `OUT` -> `D27` signal pin
- `VCC` -> `V` pin with jumper set to `3.3V`
- `GND` -> `G` pin

### MAX9814

- `OUT` -> `D34` signal pin
- `VCC` -> `V` pin with jumper set to `3.3V`
- `GND` -> `G` pin
- `GAIN` -> leave floating for default gain, or tie to ground only if you intentionally want lower gain
- `AR` / attack-release pin -> leave as the module default unless you are deliberately tuning the analog hardware behavior

### MC-38 Reed Switch

- one wire -> `D32` signal pin
- other wire -> `G` pin

The reed switch does not use the `V` rail.

### WS2812 3-LED Strip

- `DIN` -> `D25` signal pin through a `330-470 ohm` series resistor
- `5V` -> dedicated `5V` breakout on the baseplate or `VIN` breakout, not the shared `V` row when the jumper is set to `3.3V`
- `GND` -> common `GND`

Also add:

- `470-1000 uF` capacitor across LED `5V` and `GND`, physically near the LED power feed

## 7. Quick Map

| Sentinel Function | ESP32 Label On Board | Baseplate Use |
| :--- | :--- | :--- |
| BME280 SDA | `D21` | `S` pin for `D21` |
| BME280 SCL | `D22` | `S` pin for `D22` |
| PIR OUT | `D27` | `S` pin for `D27` |
| MAX9814 OUT | `D34` | `S` pin for `D34` |
| Reed signal | `D32` | `S` pin for `D32` |
| WS2812 DIN | `D25` | `S` pin for `D25` via series resistor |
| Sensor power | `3.3V` selected on jumper | `V` row |
| Sensor ground | `GND` | `G` row |
| LED power | `VIN` or dedicated `5V` breakout | direct 5V feed |
| LED ground | `GND` | common ground |

## 8. Physical Wiring Checklist

Work in this order so power stays simple while you build:

1. Plug the 30-pin ESP32 into the baseplate with the printed pin labels matching the baseplate breakout labels.
2. Set the baseplate jumper to `3.3V` before attaching any sensor power leads.
3. Wire all 3.3V sensors first.
4. Wire the reed switch.
5. Wire the WS2812 strip last, including its resistor and capacitor.
6. Power the build from the ESP32 USB-C only for the first test.

| Check | From | To | Notes |
| :--- | :--- | :--- | :--- |
| ESP32 mounted | ESP32 dev board | baseplate socket headers | Confirm header labels line up with the printed baseplate labels |
| Jumper set | `JUMP` block | `3.3V` selected | Do this before sensor power wiring |
| BME280 data 1 | BME280 `SDA` | `D21` `S` pin | I2C data |
| BME280 data 2 | BME280 `SCL` | `D22` `S` pin | I2C clock |
| BME280 power | BME280 `VCC` and `GND` | baseplate `V` and `G` | Safe because jumper is set to `3.3V` |
| PIR signal | AM312 `OUT` | `D27` `S` pin | Digital motion signal |
| PIR power | AM312 `VCC` and `GND` | baseplate `V` and `G` | Uses the shared 3.3V sensor rail |
| Mic signal | MAX9814 `OUT` | `D34` `S` pin | Analog input |
| Mic power | MAX9814 `VCC` and `GND` | baseplate `V` and `G` | Leave `GAIN` floating unless intentionally changing gain |
| Reed lead 1 | MC-38 wire 1 | `D32` `S` pin | Dry contact input |
| Reed lead 2 | MC-38 wire 2 | baseplate `G` | No `V` connection used |
| LED data | WS2812 `DIN` | `D25` `S` pin | Add `330-470 ohm` series resistor in line |
| LED power | WS2812 `5V` and `GND` | dedicated `5V` breakout and common `GND` | Do not use the shared `V` row for this |
| LED capacitor | `470-1000 uF` capacitor | across LED `5V` and `GND` | Place near the LED power entry |
| First power test | USB cable | ESP32 USB-C | Avoid barrel jack and baseplate `USB5V` for first bring-up |

## 9. Recommended Build Notes

- Keep the `V` jumper on `3.3V` for the normal sensor rows.
- Keep the LED data resistor close to the LED strip input, not back near the ESP32 if possible.
- Keep the LED bulk capacitor close to the LED power feed.
- Do not mix up the mirrored `S/V/G` row orientation between the upper and lower header banks.
- If a Dupont lead feels loose, replace it instead of trusting it inside the enclosure.

## 10. Scope

This guide is for the baseplate / Dupont implementation path using the existing AITRIP kit. It does not replace the schematic reference, but it is the practical build reference for the current hardware.

## 11. Bring-Up Checklist

Use this after the wiring is complete.

1. Verify the baseplate jumper is still on `3.3V`.
2. Confirm the WS2812 strip is powered from `5V` or `VIN`, not the shared sensor `V` row.
3. Check that the LED strip ground, sensor ground, and ESP32 ground are common.
4. Inspect the upper and lower baseplate rows against the silk so no `S/V/G` pins are mirrored by mistake.
5. Power the board from ESP32 USB-C only.
6. Confirm the ESP32 boots and is detected normally over USB.
7. Verify I2C sensor discovery for the BME280.
8. Check PIR state changes.
9. Check the reed switch open/closed state.
10. Check microphone readings move with nearby sound.
11. Test the 3-pixel WS2812 chain before closing the enclosure.

### Fast Fault Isolation

| Symptom | Most likely first check |
| :--- | :--- |
| BME280 missing | recheck `D21` / `D22` and `3.3V` power |
| PIR always stuck | confirm `OUT` is on `D27`, not a `V` or `G` pin |
| Reed always open/closed | confirm one side is on `D32` and the other is on `GND` only |
| Mic flatlines | recheck `D34` signal lead and `3.3V` supply |
| LEDs dark | recheck LED `5V`, common `GND`, and `D25` data path |
| LEDs glitch | move the resistor closer to `DIN` and confirm the bulk capacitor is installed |

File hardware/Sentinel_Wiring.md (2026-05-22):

# Sentinel ESP32: Complete Technical Wiring & Hardware Reference

For the current hardware build, use [hardware/Sentinel_Baseplate_Kit_Wiring.md](d:/Source%20Code/ESP32/Sent/hardware/Sentinel_Baseplate_Kit_Wiring.md) as the practical assembly guide when you are wiring the AITRIP baseplate / expansion kit.

This document provides the definitive, pin-to-pin wiring guide for the Sentinel Multi-Sensor Node. It accounts for all shared power/ground rails and the specific Normally Closed (NC) logic for security sensors.

---

## 1. The Common Rail Logic (Power & Ground)

The ESP32 board uses shared rails for the sensor and LED wiring.

- **VCC Rail (3.3V)**: Connect the ESP32 `3V3` pin to a common rail. All sensor VCC pins must jump from this rail.
- **Common Ground (GND)**: Connect one ESP32 `GND` pin to a common rail. All sensor GND pins must jump from this rail.
- **Status LED Rail (5V)**: The external WS2812 status LEDs should use the ESP32 board `5V`/`VIN` rail, not the `3V3` rail.
- **Shared Ground Rule**: The external WS2812 LED chain must share GND with the ESP32 and the sensor ground rail.

When using the photographed baseplate kit, the simplest safe setup is:

- set the baseplate `V` jumper to `3.3V`
- use the baseplate `V` row for the 3.3V sensors only
- use the dedicated `5V` breakout or `VIN` for the WS2812 strip

---

## 2. Component Pin Mapping

### A. Environmental Sensor (BME280)

- **VCC**: Shared 3.3V Rail
- **GND**: Shared GND Rail
- **SDA**: **GPIO 21**
- **SCL**: **GPIO 22**

### B. Motion Detector (AM312 Mini PIR)

- **VCC**: Shared 3.3V Rail
- **GND**: Shared GND Rail
- **OUT**: **GPIO 27** (Center Pin on most AM312 modules)

### C. Acoustic Sensor (MAX9814 Microphone)

- **VCC**: Shared 3.3V Rail
- **GND**: Shared GND Rail
- **OUT**: **GPIO 34** (Analog Input)
- **GAIN**: Leave floating for 60dB or tie to GND for 50dB.

### D. Security Sensor (MC-38 Reed Switch - Normally Closed)

- **Wire 1**: **GPIO 32**
- **Wire 2**: Shared GND Rail
- *Note: Firmware uses `INPUT_PULLUP`. Circuit is CLOSED (LOW) when magnet is present.*

### E. Status Indicator

- **Onboard LED**: Internal to **GPIO 2**
- **External Status LEDs**: `3 x WS2812` chained on **GPIO 25** data
- **LED Power**: `5V` rail
- **LED Ground**: Shared GND rail
- **LED Data Chain**: `GPIO25 -> DIN LED 1 -> DOUT LED 1 -> DIN LED 2 -> DOUT LED 2 -> DIN LED 3`
- **Recommended Protection**: `330-470 ohm` resistor in series with the data line near LED 1, plus `470-1000 uF` capacitor across LED `5V` and `GND`
- **Color Order**: Default firmware assumes `GRB`

---

## 3. Detailed Wiring Master Table

| Hardware Component | Component Pin | ESP32 GPIO / Pin | Signal Type |
| :--- | :--- | :--- | :--- |
| **BME280** | VCC | 3V3 Rail | Power |
| **BME280** | GND | GND Rail | Ground |
| **BME280** | SDA | **GPIO 21** | I2C Data |
| **BME280** | SCL | **GPIO 22** | I2C Clock |
| **AM312 PIR** | VCC | 3V3 Rail | Power |
| **AM312 PIR** | GND | GND Rail | Ground |
| **AM312 PIR** | OUT | **GPIO 27** | Digital Input |
| **MAX9814** | VCC | 3V3 Rail | Power |
| **MAX9814** | GND | GND Rail | Ground |
| **MAX9814** | OUT | **GPIO 34** | Analog Input (ADC1) |
| **MC-38 Switch** | Terminal 1 | **GPIO 32** | Digital (Pull-up) |
| **MC-38 Switch** | Terminal 2 | GND Rail | Ground |
| **WS2812 LED Chain** | VCC | 5V Rail | Power |
| **WS2812 LED Chain** | GND | GND Rail | Ground |
| **WS2812 LED Chain** | DIN (LED 1) | **GPIO 25** | Addressable Data |
| **WS2812 LED Chain** | DOUT (LED 1) | DIN (LED 2) | Data Pass-through |
| **WS2812 LED Chain** | DOUT (LED 2) | DIN (LED 3) | Data Pass-through |
| **Onboard LED** | Internal LED | **GPIO 2** | Digital Status |

---

## 4. Hardware Logic Summary

- **I2C Bus**: Standard hardware pins for ESP32.
- **Sound**: Uses ADC1 (GPIO 34) because ADC2 cannot be used while WiFi is active.
- **NC Logic**: The door reports "CLOSED" when the switch is LOW (magnet present).
- **Addressable LEDs**: All 3 external status LEDs share one GPIO data pin because WS2812 LEDs are daisy-chained and individually addressed in sequence.
- **Power Separation**: Sensors stay on `3V3`; the external WS2812 chain uses `5V`.
- **Grounding Requirement**: The LED chain will not work reliably unless the LED ground and ESP32 ground are tied together.

---

## 5. Final Expected Connections

| Sentinel function | Connect to | Power source |
| :--- | :--- | :--- |
| BME280 SDA | `D21` | `3.3V` |
| BME280 SCL | `D22` | `3.3V` |
| AM312 PIR OUT | `D27` | `3.3V` |
| MAX9814 OUT | `D34` | `3.3V` |
| MC-38 reed wire 1 | `D32` | none |
| MC-38 reed wire 2 | `GND` | none |
| WS2812 DIN | `D25` through `330-470 ohm` series resistor | n/a |
| WS2812 power | dedicated `5V` breakout or `VIN` | `5V` |
| WS2812 ground | `GND` | common ground |

When using the photographed AITRIP baseplate / expansion kit, keep the baseplate `V` jumper set to `3.3V` so the shared `V` row remains safe for the BME280, PIR, and MAX9814. Do not power the WS2812 strip from that shared `V` row.

---
Created for Hartmann Studio Creations Project Sentinel - May 2026

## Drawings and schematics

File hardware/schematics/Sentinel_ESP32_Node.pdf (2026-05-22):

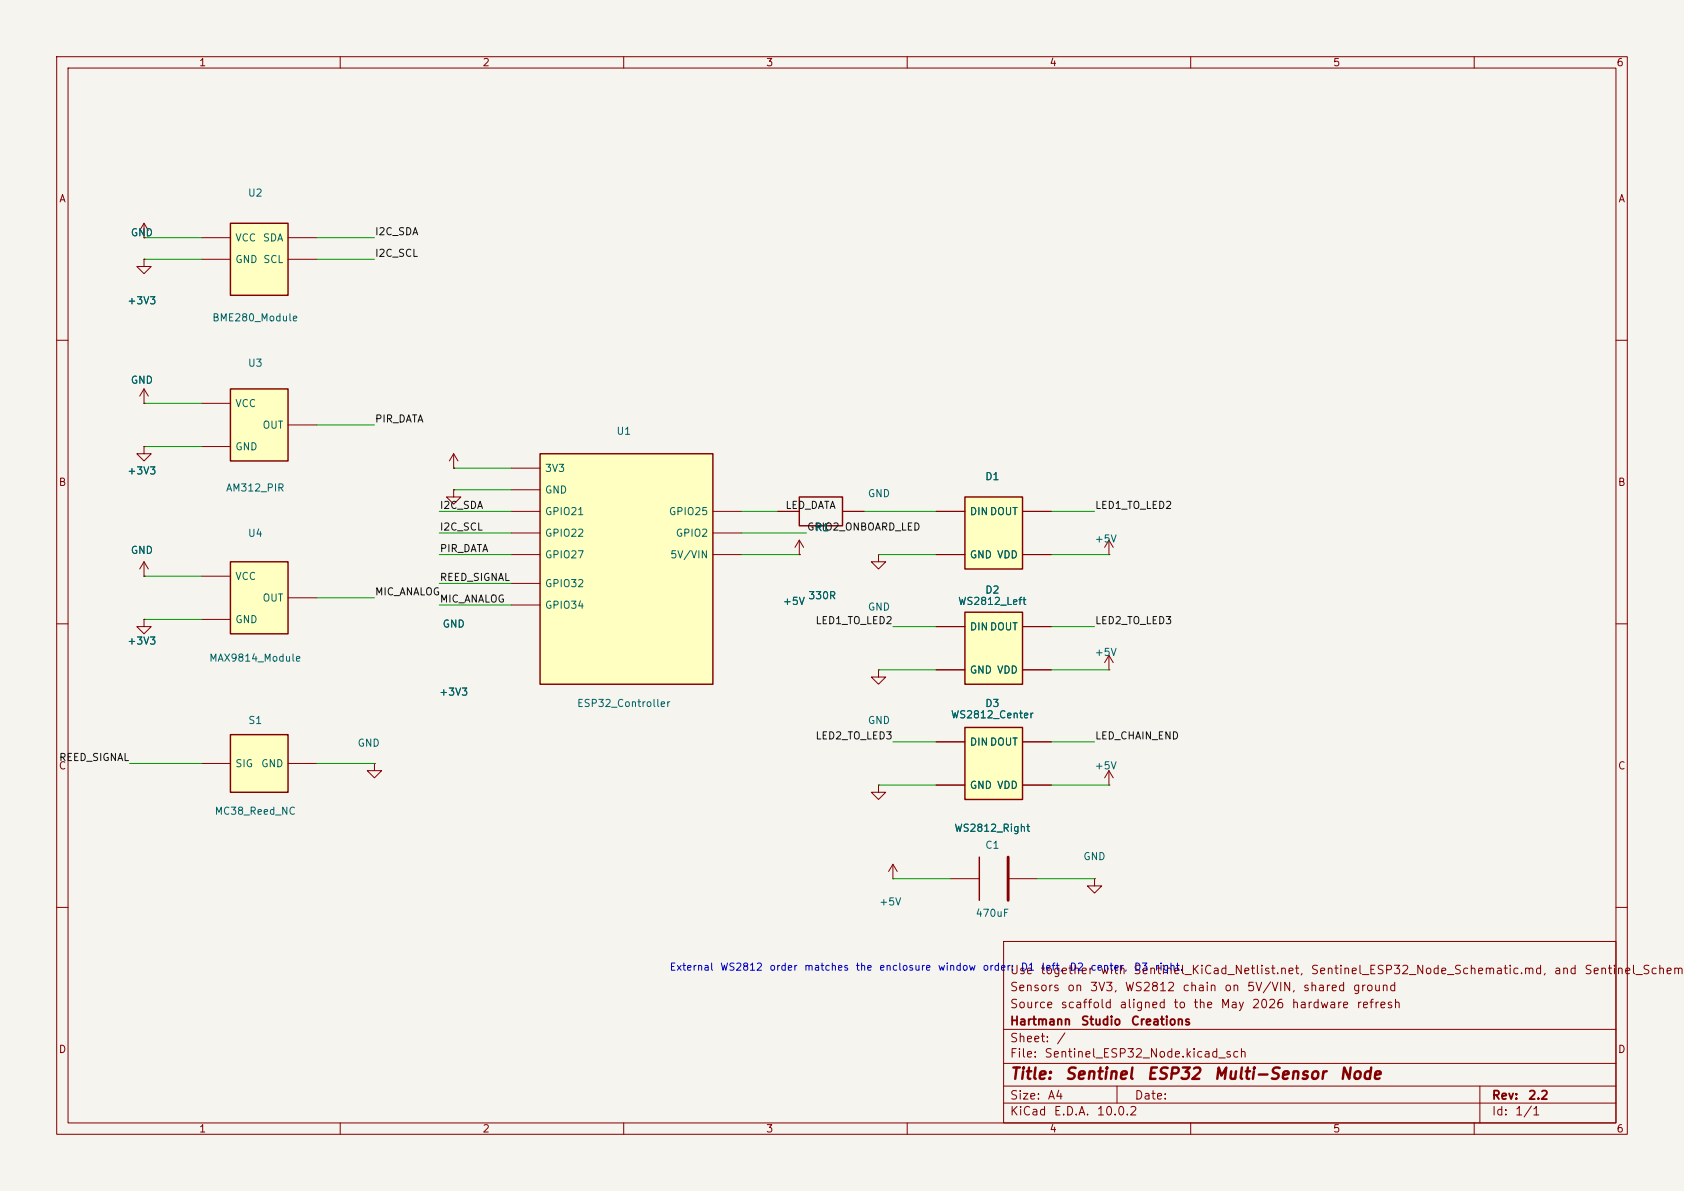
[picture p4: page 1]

D1 WS2812_Left DIN DOUT GND VDD +5V R1

D3 WS2812_Right DIN DOUT GND VDD

Use together with Sentinel_KiCad_Netlist.net, Sentinel_ESP32_Node_Schematic.md, and Sentinel_Schematic_BOM.md
Sensors on 3V3, WS2812 chain on 5V/VIN, shared ground
Source scaffold aligned to the May 2026 hardware refresh
Hartmann Studio Creations
Sheet: /
File: Sentinel_ESP32_Node.kicad_sch
Title: Sentinel ESP32 Multi-Sensor Node

Size: A4 | Rev: 2.2
KiCad E.D.A. 10.0.2 | Id: 1/1

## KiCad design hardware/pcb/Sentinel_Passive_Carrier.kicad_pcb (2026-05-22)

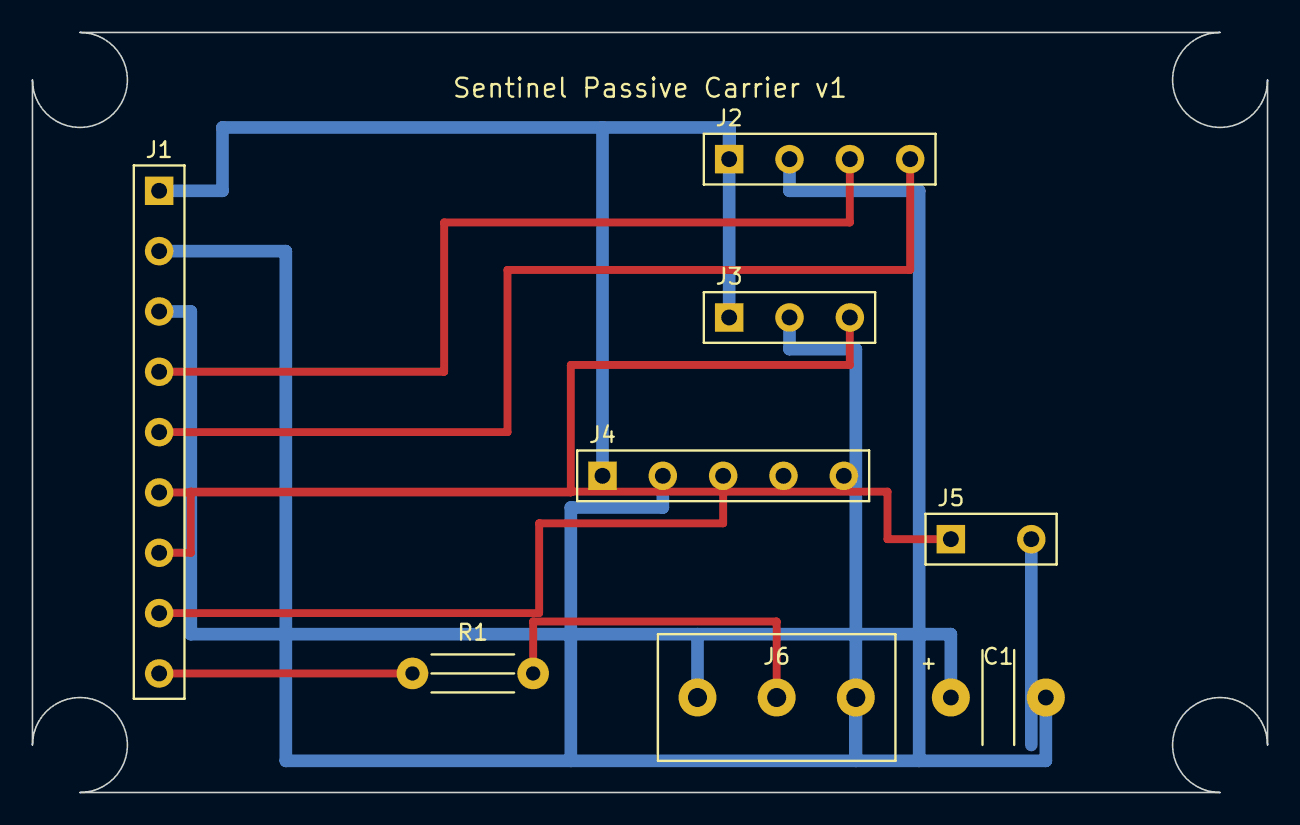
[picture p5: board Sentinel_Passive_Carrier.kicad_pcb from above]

Board: 2 copper layers, 78.0 x 48.0 mm, 8 parts (0 on the bottom side), 10 nets.

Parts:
C1: 470uF
J1: ESP32_WIRE_HARNESS
J2: BME280
J3: AM312_PIR
J4: MAX9814
J5: REED_SWITCH
J6: LED_STRIP
R1: 330R

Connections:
3V3: J1.1, J2.1, J3.1, J4.1
5V_LED: C1.1, J1.3, J6.1
GND: C1.2, J1.2, J2.2, J3.2, J4.2, J5.2, J6.3
I2C_SCL: J1.5, J2.4
I2C_SDA: J1.4, J2.3
LED_DATA: J1.9, R1.1
LED_DATA_IN: J6.2, R1.2
MIC_ANALOG: J1.8, J4.3
PIR_DATA: J1.6, J3.3
REED_SIGNAL: J1.7, J5.1

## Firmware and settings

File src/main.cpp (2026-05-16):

/*
 * ============================================================================
 * SENTINEL FIRMWARE v2.0
 * ESP32 Multi-Sensor Environmental & Security Monitor
 * ============================================================================
 *
 * Features:
 * - LAN-only networking (no cloud dependencies)
 * - MAC-based unique device identity
 * - MQTT with Home Assistant auto-discovery
 * - BME280 environmental sensors (temperature °F, humidity, pressure)
 * - Comfort Index (composite thermal comfort score)
 * - Indoor Air Quality (IAQ) Score
 * - PIR motion detection
 * - Sound-level intrusion detection
 * - BLE beacon watchlist presence tracking
 * - Door/window reed switch sensor (GPIO 32)
 * - Onboard diagnostics (uptime, heap, WiFi RSSI, reconnect counts)
 *
 * Hardware:
 * - ESP32 DevKit or equivalent
 * - BME280 via I2C (SDA=21, SCL=22)
 * - PIR sensor on GPIO 27 (AM312)
 * - Analog sound sensor on GPIO 34 (MAX9814)
 * - Door reed switch on GPIO 32 (MC-38 NC, pulled HIGH = OPEN)
 *
 * Libraries required (install via Arduino Library Manager):
 * - WiFi (built-in)
 * - PubSubClient by Nick O'Leary
 * - Adafruit BME280 Library
 * - Adafruit Unified Sensor
 * - ArduinoJson by Benoit Blanchon (v6+)
 * - BLE (built-in ESP32 BLE Arduino)
 *
 * ============================================================================
 */

#include <Arduino.h>
#include <WiFi.h>
#include <PubSubClient.h>
#include <Preferences.h>
#include <Wire.h>
#include <Adafruit_Sensor.h>
#include <Adafruit_BME280.h>
#include <ArduinoJson.h>
#include <BLEDevice.h>
#include <BLEScan.h>
#include <BLEAdvertisedDevice.h>
#include <time.h>

// ============================================================================
//  USER CONFIGURATION
// ============================================================================

// Load credentials from include/secrets.h when present.
#if __has_include("secrets.h")
#include "secrets.h"
#else
// Fallback values to keep firmware buildable until secrets are configured.
const char* WIFI_SSID     = "YOUR_WIFI_SSID";
const char* WIFI_PASSWORD = "YOUR_WIFI_PASSWORD";
const bool  WIFI_USE_STATIC_IP = false;
const char* WIFI_STATIC_IP = "192.168.1.50";
const char* WIFI_GATEWAY   = "192.168.1.1";
const char* WIFI_SUBNET    = "255.255.255.0";
const char* WIFI_DNS1      = "1.1.1.1";
const char* WIFI_DNS2      = "8.8.8.8";
const bool  TIME_USE_NTP   = true;
const char* TZ_INFO        = "UTC0";
const char* NTP_SERVER_1   = "192.168.1.100";
const char* NTP_SERVER_2   = "";
const char* NTP_SERVER_3   = "";
const char* MQTT_SERVER   = "192.168.1.100";
const int   MQTT_PORT     = 1883;
const char* MQTT_USER     = "";         // leave blank if no auth
const char* MQTT_PASS     = "";         // leave blank if no auth
#endif

// ============================================================================
//  PIN DEFINITIONS
// ============================================================================

#define PIN_PIR           27
#define PIN_SOUND         34    // analog input
#define PIN_DOOR          32    // reed switch (NC, pulled HIGH internally)
#define PIN_LED           2     // onboard status LED
#define BME_SDA           21
#define BME_SCL           22

// ============================================================================
//  TIMING INTERVALS & THRESHOLDS (milliseconds)
// ============================================================================

#define INTERVAL_ENV        30000   // environmental readings every 30s
#define INTERVAL_DIAG       60000   // diagnostics every 60s
#define INTERVAL_BLE         120000  // BLE scan every 2 minutes
#define BLE_SCAN_DURATION_MS 10000   // each BLE scan runs for 10s
#define BLE_PRESENCE_TIMEOUT_MS 150000 // mark a watched beacon away if unseen for about 2.5 minutes
#define BLE_MAX_WATCH_BEACONS 4      // fixed-size watchlist keeps BLE lightweight
#define BLE_ENROLLMENT_CACHE_SIZE 12
#define BLE_ENROLLMENT_LOG_COOLDOWN_MS 30000
#define SOUND_SAMPLE_WINDOW_MS 100  // sound sampling window (ms)
#define SOUND_THRESHOLD_ADC   1200  // peak-to-peak ADC threshold for MAX9814
#define SOUND_HOLD_MS         3000  // keep sound intrusion latched for HA
#define PIR_COOLDOWN        10000   // motion re-trigger cooldown (ms)
#define DOOR_DEBOUNCE       50      // door switch debounce (ms)
#define PIR_WARMUP_MS       30000   // AM312 settle time after power-up
#define PIR_DETECT_STABLE_MS 150    // HIGH must stay stable this long before detection
#define PIR_CLEAR_STABLE_MS 1500    // LOW must stay stable this long before clear
#define PIR_HOLD_MS         5000    // keep motion latched this long after last HIGH

// ============================================================================
//  RUNTIME CONFIG (NVS + compile-time defaults)
// ============================================================================

struct RuntimeConfig {
  String wifiSsid;
  String wifiPassword;
  bool useStaticIp;
  String staticIp;
  String gateway;
  String subnet;
  String dns1;
  String dns2;
  bool useNtp;
  String tzInfo;
  String ntpServer1;
  String ntpServer2;
  String ntpServer3;
  String mqttServer;
  int mqttPort;
  String mqttUser;
  String mqttPass;
  unsigned long pirWarmupMs;
  unsigned long pirDetectStableMs;
  unsigned long pirClearStableMs;
  unsigned long pirHoldMs;
  unsigned long soundSampleWindowMs;
  unsigned long soundHoldMs;
  unsigned long soundThresholdAdc;
  String bleBeaconNames[BLE_MAX_WATCH_BEACONS];
  String bleBeaconUuids[BLE_MAX_WATCH_BEACONS];
  unsigned long bleBeaconMajors[BLE_MAX_WATCH_BEACONS];
  unsigned long bleBeaconMinors[BLE_MAX_WATCH_BEACONS];
};

// ============================================================================
//  GLOBAL OBJECTS & STATE
// ============================================================================

WiFiClient   espClient;
PubSubClient mqttClient(espClient);
Adafruit_BME280 bme;
BLEScan* pBLEScan = nullptr;
Preferences prefs;

RuntimeConfig runtimeConfig;
bool configLoadedFromNvs = false;

const uint16_t CONFIG_VERSION = 2;
const char* CONFIG_NAMESPACE = "sentinel_cfg";

// MAC-based identity
String deviceMAC;
String deviceID;
String deviceName;
// MQTT topic base
String topicBase;

// Timing trackers
unsigned long lastEnvRead    = 0;
unsigned long lastDiagPub    = 0;
unsigned long lastBLEScan    = 0;
unsigned long lastMotionPub  = 0;

// Sensor state
bool     bmeAvailable       = false;
bool     lastDoorState      = HIGH;
// HIGH = CLOSED (pull-up) for NO switch; logic flipped for NC in publishDoorState
bool     currentDoorState   = HIGH;
unsigned long lastDoorChange = 0;
bool     motionDetected     = false;
bool     soundIntrusionActive = false;
unsigned long pirWarmupUntil = 0;
unsigned long pirHighSince   = 0;
unsigned long pirLowSince    = 0;
unsigned long pirHoldUntil   = 0;
unsigned long soundHoldUntil = 0;
int          pirLastRawState = LOW;

bool beaconPresent[BLE_MAX_WATCH_BEACONS] = {false, false, false, false};
int beaconRssi[BLE_MAX_WATCH_BEACONS] = {0, 0, 0, 0};
unsigned long beaconLastSeenMs[BLE_MAX_WATCH_BEACONS] = {0, 0, 0, 0};
bool bleEnrollmentLoggingEnabled = false;
String bleEnrollmentSeenIds[BLE_ENROLLMENT_CACHE_SIZE];
unsigned long bleEnrollmentSeenMs[BLE_ENROLLMENT_CACHE_SIZE] = {0};

// Diagnostics counters
unsigned long wifiReconnects = 0;
unsigned long mqttReconnects = 0;
unsigned long bootTime       = 0;

// ============================================================================
//  FORWARD DECLARATIONS
// ============================================================================

void setupIdentity();
void loadRuntimeConfigDefaults();
bool validateRuntimeConfig(const RuntimeConfig& cfg);
void loadRuntimeConfig();
bool saveRuntimeConfigToNvs();
bool clearRuntimeConfigFromNvs();
void printRuntimeConfig();
bool parseBoolValue(const String& rawValue, bool& outValue);
bool setRuntimeConfigValue(const String& key, const String& value);
void applyRuntimeConfigNow();
void processSerialCommand(String line);
void handleSerialCommands();
void setupWiFi();
void applyWiFiNetworkConfig();
void setupTimeSync();
void setupMQTT();
void setupBME280();
void setupPIR();
void setupDoor();
void setupBLE();
void setupLED();

void reconnectWiFi();
void reconnectMQTT();
void publishAutoDiscovery();
void publishPirConfigDiscovery();
void publishPirConfigState();
void publishSoundConfigDiscovery();
void publishSoundConfigState();
void publishBeaconDiscovery();
void publishBeaconState(bool initialPublish = false);
void publishBeaconConfigDiscovery();
void publishBeaconConfigState();
void clearLegacyBleTopics();
void publishSoundState(const char* intrusionState, int peakToPeak, int minSample, int maxSample);
void mqttMessageCallback(char* topic, byte* payload, unsigned int length);
bool handlePirConfigCommand(const String& topic, const String& payload);
bool handleSoundConfigCommand(const String& topic, const String& payload);
bool handleBeaconConfigCommand(const String& topic, const String& payload);

void readAndPublishEnvironment();
void publishDoorState(bool state);
void checkMotion();
void checkSound();
void checkDoor();
void runBLEScan();
bool normalizeUuid(const String& rawUuid, String& normalizedUuid);
String defaultBeaconName(size_t index);
String beaconDisplayName(size_t index);
bool isBeaconConfigured(size_t index);
void processBleScanResult(BLEAdvertisedDevice advertisedDevice);
bool parseIBeaconAdvertisement(BLEAdvertisedDevice advertisedDevice, String& uuid, uint16_t& major, uint16_t& minor);
void logIBeaconSighting(const String& uuid, uint16_t major, uint16_t minor, int rssi);
void processBeaconAdvertisement(const String& uuid, uint16_t major, uint16_t minor, int rssi);
void expireBeaconPresence(unsigned long nowMs);
void publishDiagnostics();

float  computeComfortIndex(float tempF, float humidity);
int    computeIAQScore(float humidity, float pressureHPa);
String comfortLabel(float index);
String iaqLabel(int score);
uint32_t currentTimestampSeconds();
void   mqttPublish(const char* topic, const char* payload, bool retained = false);

// ============================================================================
//  SETUP
// ============================================================================

void setup() {
  Serial.begin(115200);
  delay(500);
  Serial.println();
  Serial.println(F("========================================"));
  Serial.println(F("  SENTINEL FIRMWARE v2.0"));
  Serial.println(F("  Multi-Sensor Security & Environment"));
  Serial.println(F("========================================"));

  loadRuntimeConfig();
  setupIdentity();
  setupLED();
  setupWiFi();
  setupMQTT();
  setupBME280();
  setupPIR();
  setupDoor();
  setupBLE();

  bootTime = millis();
  // Connect MQTT and publish auto-discovery
  reconnectMQTT();
  if (mqttClient.connected()) {
    clearLegacyBleTopics();
    publishAutoDiscovery();
    publishPirConfigDiscovery();
    publishPirConfigState();
    publishSoundConfigDiscovery();
    publishSoundConfigState();
    publishSoundState("clear", 0, 0, 0);
    publishBeaconDiscovery();
    publishBeaconConfigDiscovery();
    publishBeaconConfigState();
    publishBeaconState(true);
    // Publish initial door state at boot
    currentDoorState = digitalRead(PIN_DOOR);
    lastDoorState = currentDoorState;
    publishDoorState(currentDoorState);
    Serial.printf("[DOOR] Boot state: %s\n", currentDoorState == LOW ? "CLOSED" : "OPEN");

    // Publish initial environment reading
    readAndPublishEnvironment();
    // Publish initial diagnostics
    publishDiagnostics();
  }

  Serial.println(F("[SYSTEM] Setup complete — entering main loop"));
  Serial.println(F("[SYSTEM] Serial config: cfg list"));
  Serial.println();
}

// ============================================================================
//  MAIN LOOP
// ============================================================================

void loop() {
  handleSerialCommands();

  // Maintain connections
  if (WiFi.status() != WL_CONNECTED) {
    reconnectWiFi();
  }
  if (!mqttClient.connected()) {
    reconnectMQTT();
  }
  mqttClient.loop();

  unsigned long now = millis();
  // Environmental readings (BME280 + Comfort + IAQ)
  if (now - lastEnvRead >= INTERVAL_ENV) {
    lastEnvRead = now;
    readAndPublishEnvironment();
  }

  // Motion detection (interrupt-style polling)
  checkMotion();

  // Sound intrusion detection
  checkSound();

  // Door state monitoring
  checkDoor();

  // BLE beacon watchlist scan
  if (now - lastBLEScan >= INTERVAL_BLE) {
    lastBLEScan = now;
    runBLEScan();
  }

  // Diagnostics
  if (now - lastDiagPub >= INTERVAL_DIAG) {
    lastDiagPub = now;
    publishDiagnostics();
  }

  delay(10);  // yield
}

// ============================================================================
//  IDENTITY — MAC-based unique device ID
// ============================================================================

void setupIdentity() {
  uint8_t mac[6];
  WiFi.macAddress(mac);
  char macStr[18];
  snprintf(macStr, sizeof(macStr), "%02X:%02X:%02X:%02X:%02X:%02X",
           mac[0], mac[1], mac[2], mac[3], mac[4], mac[5]);
  deviceMAC = String(macStr);

  char idStr[13];
  snprintf(idStr, sizeof(idStr), "%02x%02x%02x%02x%02x%02x",
           mac[0], mac[1], mac[2], mac[3], mac[4], mac[5]);
  deviceID = String(idStr);

  deviceName = "sentinel_" + deviceID;
  topicBase  = "sentinel/" + deviceID;

  Serial.printf("[IDENTITY] MAC: %s\n", deviceMAC.c_str());
  Serial.printf("[IDENTITY] Device ID: %s\n", deviceID.c_str());
  Serial.printf("[IDENTITY] Name: %s\n", deviceName.c_str());
  Serial.printf("[IDENTITY] Topic base: %s\n", topicBase.c_str());
}

void loadRuntimeConfigDefaults() {
  runtimeConfig.wifiSsid = WIFI_SSID;
  runtimeConfig.wifiPassword = WIFI_PASSWORD;
  runtimeConfig.useStaticIp = WIFI_USE_STATIC_IP;
  runtimeConfig.staticIp = WIFI_STATIC_IP;
  runtimeConfig.gateway = WIFI_GATEWAY;
  runtimeConfig.subnet = WIFI_SUBNET;
  runtimeConfig.dns1 = WIFI_DNS1;
  runtimeConfig.dns2 = WIFI_DNS2;
  runtimeConfig.useNtp = TIME_USE_NTP;
  runtimeConfig.tzInfo = TZ_INFO;
  runtimeConfig.ntpServer1 = NTP_SERVER_1;
  runtimeConfig.ntpServer2 = NTP_SERVER_2;
  runtimeConfig.ntpServer3 = NTP_SERVER_3;
  runtimeConfig.mqttServer = MQTT_SERVER;
  runtimeConfig.mqttPort = MQTT_PORT;
  runtimeConfig.mqttUser = MQTT_USER;
  runtimeConfig.mqttPass = MQTT_PASS;
  runtimeConfig.pirWarmupMs = PIR_WARMUP_MS;
  runtimeConfig.pirDetectStableMs = PIR_DETECT_STABLE_MS;
  runtimeConfig.pirClearStableMs = PIR_CLEAR_STABLE_MS;
  runtimeConfig.pirHoldMs = PIR_HOLD_MS;
  runtimeConfig.soundSampleWindowMs = SOUND_SAMPLE_WINDOW_MS;
  runtimeConfig.soundHoldMs = SOUND_HOLD_MS;
  runtimeConfig.soundThresholdAdc = SOUND_THRESHOLD_ADC;
  for (size_t i = 0; i < BLE_MAX_WATCH_BEACONS; i++) {
    runtimeConfig.bleBeaconNames[i] = defaultBeaconName(i);
    runtimeConfig.bleBeaconUuids[i] = "";
    runtimeConfig.bleBeaconMajors[i] = 0;
    runtimeConfig.bleBeaconMinors[i] = 0;
  }
}

bool validateRuntimeConfig(const RuntimeConfig& cfg) {
  if (cfg.wifiSsid.length() == 0 || cfg.mqttServer.length() == 0) {
    return false;
  }
  if (cfg.mqttPort < 1 || cfg.mqttPort > 65535) {
    return false;
  }
  if (cfg.pirWarmupMs > 300000 ||
      cfg.pirDetectStableMs < 10 || cfg.pirDetectStableMs > 10000 ||
      cfg.pirClearStableMs < 50 || cfg.pirClearStableMs > 60000 ||
      cfg.pirHoldMs < 250 || cfg.pirHoldMs > 60000 ||
      cfg.soundSampleWindowMs < 10 || cfg.soundSampleWindowMs > 1000 ||
      cfg.soundHoldMs < 100 || cfg.soundHoldMs > 60000 ||
      cfg.soundThresholdAdc < 10 || cfg.soundThresholdAdc > 4095) {
    return false;
  }
  for (size_t i = 0; i < BLE_MAX_WATCH_BEACONS; i++) {
    if (cfg.bleBeaconUuids[i].length() == 0) {
      continue;
    }

    String normalizedUuid;
    if (!normalizeUuid(cfg.bleBeaconUuids[i], normalizedUuid)) {
      return false;
    }
    if (cfg.bleBeaconMajors[i] > 65535 || cfg.bleBeaconMinors[i] > 65535) {
      return false;
    }
  }
  if (!cfg.useStaticIp) {
    return true;
  }

  IPAddress localIp;
  IPAddress gateway;
  IPAddress subnet;
  IPAddress dns1;
  IPAddress dns2;

  return localIp.fromString(cfg.staticIp) &&
         gateway.fromString(cfg.gateway) &&
         subnet.fromString(cfg.subnet) &&
         dns1.fromString(cfg.dns1) &&
         dns2.fromString(cfg.dns2);
}

void loadRuntimeConfig() {
  loadRuntimeConfigDefaults();
  configLoadedFromNvs = false;

  if (!prefs.begin(CONFIG_NAMESPACE, true)) {
    Serial.println(F("[CONFIG] NVS unavailable; using compile-time defaults"));
    return;
  }

  const uint16_t storedVersion = prefs.getUShort("cfg_ver", 0);
  if (storedVersion != CONFIG_VERSION) {
    Serial.printf("[CONFIG] No matching config version in NVS (found %u, need %u); using defaults\n",
                  storedVersion, CONFIG_VERSION);
    prefs.end();
    return;
  }

  RuntimeConfig nvsConfig = runtimeConfig;
  nvsConfig.wifiSsid = prefs.getString("wifi_ssid", runtimeConfig.wifiSsid);
  nvsConfig.wifiPassword = prefs.getString("wifi_pass", runtimeConfig.wifiPassword);
  nvsConfig.useStaticIp = prefs.getBool("st_ip_en", runtimeConfig.useStaticIp);
  nvsConfig.staticIp = prefs.getString("st_ip", runtimeConfig.staticIp);
  nvsConfig.gateway = prefs.getString("gw", runtimeConfig.gateway);
  nvsConfig.subnet = prefs.getString("subnet", runtimeConfig.subnet);
  nvsConfig.dns1 = prefs.getString("dns1", runtimeConfig.dns1);
  nvsConfig.dns2 = prefs.getString("dns2", runtimeConfig.dns2);
  nvsConfig.useNtp = prefs.getBool("use_ntp", runtimeConfig.useNtp);
  nvsConfig.tzInfo = prefs.getString("tz", runtimeConfig.tzInfo);
  nvsConfig.ntpServer1 = prefs.getString("ntp1", runtimeConfig.ntpServer1);
  nvsConfig.ntpServer2 = prefs.getString("ntp2", runtimeConfig.ntpServer2);
  nvsConfig.ntpServer3 = prefs.getString("ntp3", runtimeConfig.ntpServer3);
  nvsConfig.mqttServer = prefs.getString("mqtt_srv", runtimeConfig.mqttServer);
  nvsConfig.mqttPort = prefs.getInt("mqtt_prt", runtimeConfig.mqttPort);
  nvsConfig.mqttUser = prefs.getString("mqtt_usr", runtimeConfig.mqttUser);
  nvsConfig.mqttPass = prefs.getString("mqtt_pwd", runtimeConfig.mqttPass);
  nvsConfig.pirWarmupMs = prefs.getULong("pir_warm", runtimeConfig.pirWarmupMs);
  nvsConfig.pirDetectStableMs = prefs.getULong("pir_det", runtimeConfig.pirDetectStableMs);
  nvsConfig.pirClearStableMs = prefs.getULong("pir_clr", runtimeConfig.pirClearStableMs);
  nvsConfig.pirHoldMs = prefs.getULong("pir_hold", runtimeConfig.pirHoldMs);
  nvsConfig.soundSampleWindowMs = prefs.getULong("snd_win", runtimeConfig.soundSampleWindowMs);
  nvsConfig.soundHoldMs = prefs.getULong("snd_hold", runtimeConfig.soundHoldMs);
  nvsConfig.soundThresholdAdc = prefs.getULong("snd_thr", runtimeConfig.soundThresholdAdc);
  for (size_t i = 0; i < BLE_MAX_WATCH_BEACONS; i++) {
    char nameKey[12];
    char uuidKey[12];
    char majorKey[12];
    char minorKey[12];
    snprintf(nameKey, sizeof(nameKey), "bcn%u_name", (unsigned)(i + 1));
    snprintf(uuidKey, sizeof(uuidKey), "bcn%u_uuid", (unsigned)(i + 1));
    snprintf(majorKey, sizeof(majorKey), "bcn%u_maj", (unsigned)(i + 1));
    snprintf(minorKey, sizeof(minorKey), "bcn%u_min", (unsigned)(i + 1));
    nvsConfig.bleBeaconNames[i] = prefs.getString(nameKey, runtimeConfig.bleBeaconNames[i]);
    nvsConfig.bleBeaconUuids[i] = prefs.getString(uuidKey, runtimeConfig.bleBeaconUuids[i]);
    nvsConfig.bleBeaconMajors[i] = prefs.getULong(majorKey, runtimeConfig.bleBeaconMajors[i]);
    nvsConfig.bleBeaconMinors[i] = prefs.getULong(minorKey, runtimeConfig.bleBeaconMinors[i]);
  }
  prefs.end();

  if (!validateRuntimeConfig(nvsConfig)) {
    Serial.println(F("[CONFIG] NVS config invalid; using compile-time defaults"));
    return;
  }

  runtimeConfig = nvsConfig;
  configLoadedFromNvs = true;
  Serial.println(F("[CONFIG] Loaded runtime config from NVS"));
}
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

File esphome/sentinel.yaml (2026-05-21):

# ESPHome port of the Sentinel node.
#
# Keeps what ESPHome is good at:
# - Wi-Fi + native API/Home Assistant integration
# - BME280 environment telemetry
# - PIR motion, reed switch door, and MAX9814 sound detection
# - Runtime tuning through Home Assistant number entities
#

substitutions:
  device_name: sentinel
  friendly_name: Sentinel
  fallback_ap_password: change-me-1234
  status_pixel_pin: "25"
  status_pixel_rgb_order: GRB

esphome:
  name: ${device_name}
  friendly_name: ${friendly_name}
  comment: Sentinel ESP32 node
  project:
    name: sentinel.node
    version: "0.1"
  on_boot:
    priority: -100
    then:
      - script.execute: reset_runtime_states
      - lambda: |-
          id(boot_count) += 1;
          id(wifi_connected_state) = false;
          id(api_client_count) = 0;
          id(pir_warmup_until_ms) = millis() + (uint32_t) id(pir_warmup_ms).state;
      - binary_sensor.template.publish:
          id: wifi_connected
          state: false
      - binary_sensor.template.publish:
          id: api_connected
          state: false
      - if:
          condition:
            lambda: 'return id(status_pixel_auto_enabled);'
          then:
            - light.turn_on:
                id: status_pixel
                brightness: 100%
                effect: Auto Status Layout

esp32:
  board: esp32dev
  framework:
    type: arduino

preferences:
  flash_write_interval: 1min

logger:
  level: INFO

api:
  on_client_connected:
    then:
      - lambda: |-
          id(api_client_count) += 1;
      - binary_sensor.template.publish:
          id: api_connected
          state: true
  on_client_disconnected:
    then:
      - lambda: |-
          if (id(api_client_count) > 0) {
            id(api_client_count) -= 1;
          }
          id(api_disconnect_count) += 1;
          id(api_connected).publish_state(id(api_client_count) > 0);

ota:
  - platform: esphome

debug:
  update_interval: 30s

web_server:
  port: 80
  version: 3
  include_internal: false

wifi:
  ssid: !secret wifi_ssid
  password: !secret wifi_password
  on_connect:
    then:
      - lambda: |-
          id(wifi_connected_state) = true;
      - binary_sensor.template.publish:
          id: wifi_connected
          state: true
  on_disconnect:
    then:
      - lambda: |-
          id(wifi_connected_state) = false;
          id(wifi_disconnect_count) += 1;
      - binary_sensor.template.publish:
          id: wifi_connected
          state: false
  # Uncomment and edit if you want a fixed LAN address.
  # manual_ip:
  #   static_ip: 192.168.1.50
  #   gateway: 192.168.1.1
  #   subnet: 255.255.255.0
  #   dns1: 192.168.1.1
  #   dns2: 1.1.1.1
  ap:
    ssid: ${friendly_name} Fallback
    password: ${fallback_ap_password}

captive_portal:

status_led:
  pin:
    number: 2

i2c:
  sda: 21
  scl: 22
  scan: true
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

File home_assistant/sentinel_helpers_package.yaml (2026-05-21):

# Example Home Assistant package for Sentinel.
#
# Drop this file into your Home Assistant packages folder, for example:
#   config/packages/sentinel_helpers_package.yaml
#
# Then make sure your main configuration.yaml includes:
#   homeassistant:
#     packages: !include_dir_named packages
#
# This package intentionally keeps the higher-churn helper logic in HA instead
# of on the ESP32:
# - event counters
# - a shared last-event readout
# - a simple operating mode selector
#
# Update the entity_ids below if your Sentinel device uses different names.

counter:
  sentinel_motion_events:
    name: Sentinel Motion Events
    icon: mdi:run-fast
    step: 1

  sentinel_sound_events:
    name: Sentinel Sound Events
    icon: mdi:waveform
    step: 1

  sentinel_smoke_events:
    name: Sentinel Smoke Events
    icon: mdi:smoke-detector-alert
    step: 1

  sentinel_door_events:
    name: Sentinel Door Events
    icon: mdi:door-open
    step: 1

input_text:
  sentinel_last_event:
    name: Sentinel Last Event
    max: 255

input_datetime:
  sentinel_last_event_time:
    name: Sentinel Last Event Time
    has_date: true
    has_time: true

input_select:
  sentinel_mode:
    name: Sentinel Mode
    icon: mdi:shield-home
    options:
      - Disarmed
      - Motion Only
      - Motion + Sound
      - Full Monitor

template:
  - sensor:
      - name: Sentinel Last Event Summary
        unique_id: sentinel_last_event_summary
        icon: mdi:history
        state: >-
          {% set event_name = states('input_text.sentinel_last_event') %}
          {% set event_time = states('input_datetime.sentinel_last_event_time') %}
          {% if event_name in ['unknown', 'unavailable', ''] %}
            Idle
          {% elif event_time in ['unknown', 'unavailable', ''] %}
            {{ event_name }}
          {% else %}
            {{ event_name }} @ {{ event_time }}
          {% endif %}

automation:
  # Count motion triggers and record the latest event.
  - id: sentinel_count_motion_events
    alias: Sentinel Count Motion Events
    trigger:
      - platform: state
        entity_id: binary_sensor.sentinel_motion
        to: "on"
    action:
      - service: counter.increment
        target:
          entity_id: counter.sentinel_motion_events
      - service: input_text.set_value
        target:
          entity_id: input_text.sentinel_last_event
        data:
          value: Motion
      - service: input_datetime.set_datetime
        target:
          entity_id: input_datetime.sentinel_last_event_time
        data:
          datetime: "{{ now().strftime('%Y-%m-%d %H:%M:%S') }}"

  # Count sound intrusion triggers and record the latest event.
  - id: sentinel_count_sound_events
    alias: Sentinel Count Sound Events
    trigger:
      - platform: state
        entity_id: binary_sensor.sentinel_sound_intrusion
        to: "on"
    action:
      - service: counter.increment
        target:
          entity_id: counter.sentinel_sound_events
      - service: input_text.set_value
        target:
          entity_id: input_text.sentinel_last_event
        data:
          value: Sound intrusion
      - service: input_datetime.set_datetime
        target:
          entity_id: input_datetime.sentinel_last_event_time
        data:
          datetime: "{{ now().strftime('%Y-%m-%d %H:%M:%S') }}"

  # Count smoke events and record the latest event.
  - id: sentinel_count_smoke_events
    alias: Sentinel Count Smoke Events
    trigger:
      - platform: state
        entity_id: binary_sensor.sentinel_smoke_alarm_detected
        to: "on"
    action:
      - service: counter.increment
        target:
          entity_id: counter.sentinel_smoke_events
      - service: input_text.set_value
        target:
          entity_id: input_text.sentinel_last_event
        data:
          value: Smoke alarm
      - service: input_datetime.set_datetime
        target:
          entity_id: input_datetime.sentinel_last_event_time
        data:
          datetime: "{{ now().strftime('%Y-%m-%d %H:%M:%S') }}"

  # Count door openings and record the latest event.
  - id: sentinel_count_door_events
    alias: Sentinel Count Door Events
    trigger:
      - platform: state
        entity_id: binary_sensor.sentinel_door
        to: "on"
    action:
      - service: counter.increment
        target:
          entity_id: counter.sentinel_door_events
      - service: input_text.set_value
        target:
          entity_id: input_text.sentinel_last_event
        data:
          value: Door opened
      - service: input_datetime.set_datetime
        target:
          entity_id: input_datetime.sentinel_last_event_time
        data:
          datetime: "{{ now().strftime('%Y-%m-%d %H:%M:%S') }}"
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

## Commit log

2026-05-13 feat: add sentinel esp32 node firmware and hardware/doc scaffolding
    Agent-Logs-Url: https://github.com/Kilmanagh/Sentinel_ESP32/sessions/5bc2e0f3-658e-4ccc-94b3-6b78b24097ab
    [board_outline.gbr, bottom_copper.gbr, top_copper.gbr]
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2026-05-13 fix: align sensor sampling timing and shared readings
    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
    [Sentinel_ESP32_Node.ino]
2026-05-13 perf: sample ADC only when telemetry or heartbeat is due
    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
2026-05-13 Upgrade Sentinel ESP32 Node to firmware v2.0
    Updated the Sentinel ESP32 Node firmware to version 2.0, adding features for environmental monitoring, security, and diagnostics.
2026-05-13 Enhance Hardware Deliverables documentation
    Expanded documentation to include detailed hardware components, wiring configurations, and firmware logic adjustments for the Sentinel ESP32 Node.
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2026-05-13 Revise hardware deliverables and wiring notes
    Updated hardware configuration details and added wiring connection notes for clarity.
2026-05-13 Add MQTT Topic Map for Sentinel ESP32 Node
    This document outlines the MQTT topics and JSON payloads used by the Sentinel ESP32 Node for communication with Home Assistant, detailing the structure and frequency of various sensor data.
2026-05-13 Document wiring and specifications for Sentinel ESP32 Node
    Added detailed wiring and component specifications for the Sentinel ESP32 Node, including power distribution and sensor connections.
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2026-05-13 Add complete documentation for Sentinel ESP32 project
    This document provides comprehensive technical specifications, hardware deliverables, MQTT topic maps, and calibration guides for the Sentinel ESP32 Multi-Sensor Node.
2026-05-13 Add Sentinel ESP32 enclosure specifications document
    This document outlines the specifications for the 3D-printed enclosure of the Sentinel ESP32 Node, including physical dimensions, sensor integration requirements, and recommended print settings.
2026-05-13 Add OpenSCAD model for ESP32 Node Enclosure
    [Openscad.scad]
2026-05-13 Revise assembly and disassembly instructions
    Updated section numbers and added detailed assembly and disassembly instructions for the Sentinel Enclosure.
2026-05-13 Add wiring guide for Sentinel Multi-Sensor Node
    This document provides a comprehensive wiring guide for the Sentinel Multi-Sensor Node, detailing power and ground connections, component pin mappings, and a wiring master table.
2026-05-13 Update Sentinel ESP32 Node Enclosure design
    [Openscad.scad]
2026-05-15 Add initial implementation of Sentinel Firmware v2.0 for ESP32 multi-sensor monitor
    - Created main application file (main.cpp) with features including environmental monitoring, motion detection, sound intrusion detection, and BLE scanning.
    - Added configuration for WiFi and MQTT connectivity.
    - Implemented Home Assistant auto-discovery for sensor integration.
    - Introduced diagnostics for system health monitoring.
    - Added .gitignore file to exclude build artifacts and IDE configurations.
    - Included VSCode extensions recommendations for development environment setup.
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2026-05-16 Enhance PIR motion detection logic with warmup and stability checks
    [main.cpp]
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2026-05-16 Increase MQTT buffer size and add publish failure logging
    [main.cpp]
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2026-05-16 Refactor BLE functionality to implement beacon watchlist
    - Updated BLE scanning to focus on a fixed-size watchlist for beacons.
    - Replaced BLE device tracking with beacon-specific structures and logic.
    - Introduced new configuration options for beacon names, UUIDs, majors, and minors.
    - Enhanced MQTT discovery and state publishing for beacons.
    - Removed legacy BLE device handling and associated topics.
    - Improved UUID normalization and validation for beacons.
    - Updated diagnostics and state reporting to reflect beacon presence.
    [main.cpp]
2026-05-19 Add throttle filter to ADC template sensors and set logger level to INFO
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2026-05-20 Refactor sensor and switch names to remove friendly name prefix for clarity; add Comfort Index and IAQ Score sensors.
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2026-05-20 Add reset_runtime_states script and button to initialize detection states
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2026-05-20 Add smoke alarm beep count and last beep age sensors: enhance detection metrics for improved monitoring
2026-05-20 Add sound calibration features: implement capture duration, baseline, and reference settings for improved sound detection
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2026-05-21 Add device health diagnostics: implement WiFi and API connection states, boot count, and memory metrics for improved monitoring
2026-05-21 Fix smoke profile retrieval: use current_option() for default value fallback
2026-05-21 Fix smoke profile retrieval: ensure default value is set when current option is empty
2026-05-21 Enhance status LED functionality: implement multiple LEDs for system health, activity, and alerts with new controls and troubleshooting options
2026-05-21 Add switches for PIR, sound, and smoke alarm sensing; enhance status LED configuration
2026-05-21 Enhance wiring documentation: add detailed information for WS2812 LED chain, including power, ground, and data connections
2026-05-21 Add status LED meaning sensors: implement left, center, and right LED meaning indicators for enhanced diagnostics
2026-05-21 Refactor status LED entity types: update to use sensor entities for LED meanings and clean up unnecessary whitespace in the dashboard YAML
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2026-05-22 Add Sentinel ESP32 Enclosure documentation and specifications
    - Created Sentinel_Enclosure.md for assembly, installation, and service notes for the v2_7 enclosure layout.
    - Added Sentinel_Enclosure_Guide.stl for a simplified geometric representation of the enclosure.
    - Introduced Sentinel_Enclosure_Specs.md detailing the mechanical design, dimensions, and features of the v2_7 enclosure.
    [Openscad_LED_Lid_v2_7_barholder.scad, Openscad_LED_Lid_v2_7_barholder.stl, Sentinel_Enclosure_Guide.stl]
2026-05-22 Add schematic files and BOM for Sentinel ESP32 Node
    - Created ERC report for Sentinel ESP32 Node schematic, highlighting symbol mismatches and library issues.
    - Added netlist file for Sentinel ESP32 Node, detailing components and connections.
    - Introduced a Bill of Materials (BOM) and connection landing table for the Sentinel ESP32 Node, outlining component specifications and wiring details.
    [Sentinel_ESP32_Node.kicad_sch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]
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
